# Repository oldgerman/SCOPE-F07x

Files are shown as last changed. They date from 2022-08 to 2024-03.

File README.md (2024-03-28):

# [SCOPE-F07x](https://github.com/oldgerman/SCOPE-F07x)

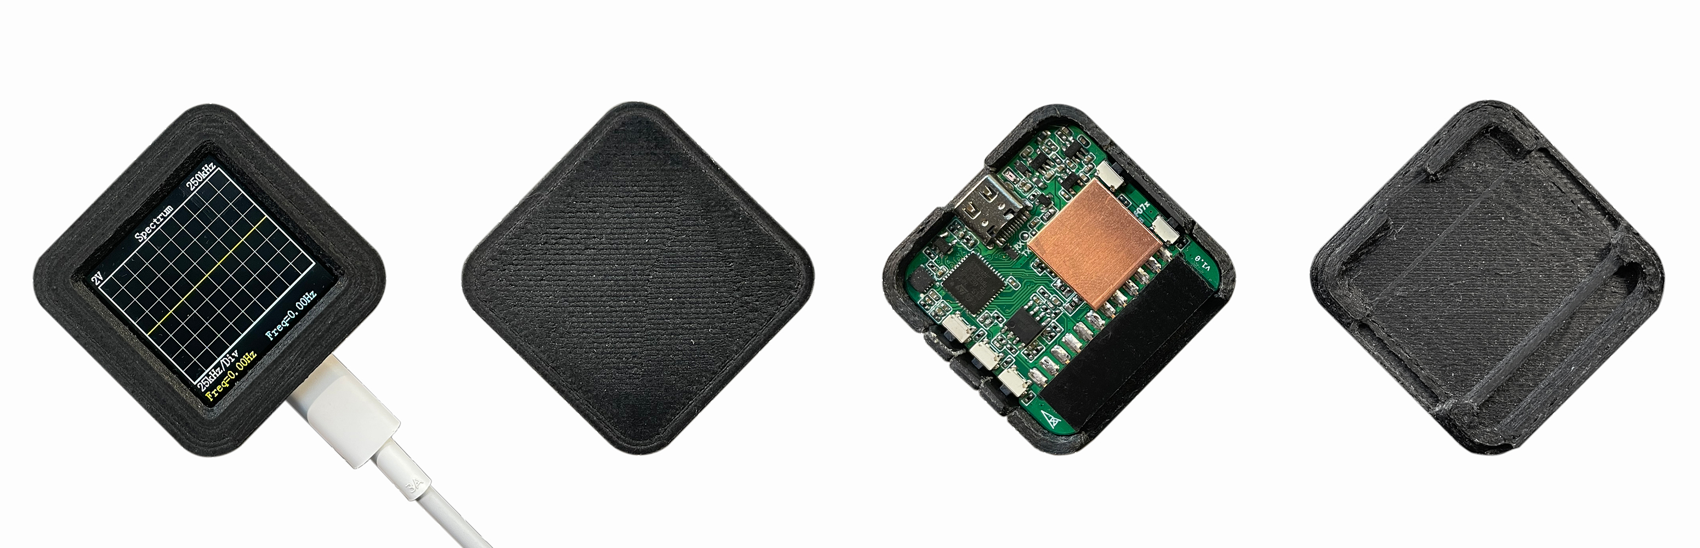
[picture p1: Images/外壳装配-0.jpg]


### 关于

[SCOPE-F07x](https://github.com/oldgerman/SCOPE-F07x) 从 [硬禾SCOPE-F072](https://github.com/EETree-git/SCOPE-F072) 开源和公开资料修改&优化

零零散散修改的地方比较多，详见修改说明部分

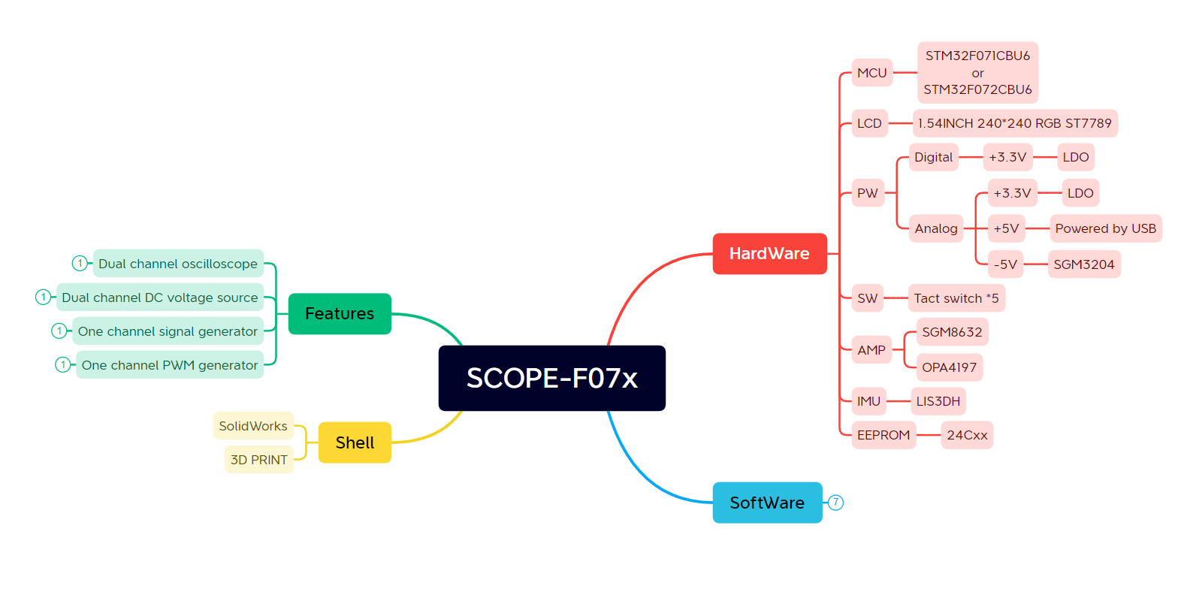
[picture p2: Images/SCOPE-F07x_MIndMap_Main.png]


### PCB

工艺：

- 层数：2
- 板厚: 1.0mm 
- 过孔: 0.3/0.5mm
- 线宽线隙: 6mil/6mil
- 尺寸: 38x38mm

封装：绝大多数是0402，物料约40多种

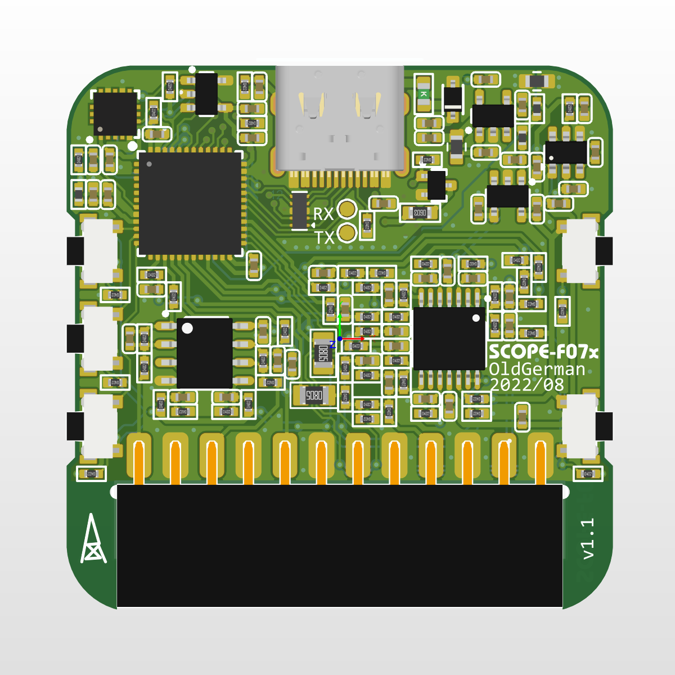
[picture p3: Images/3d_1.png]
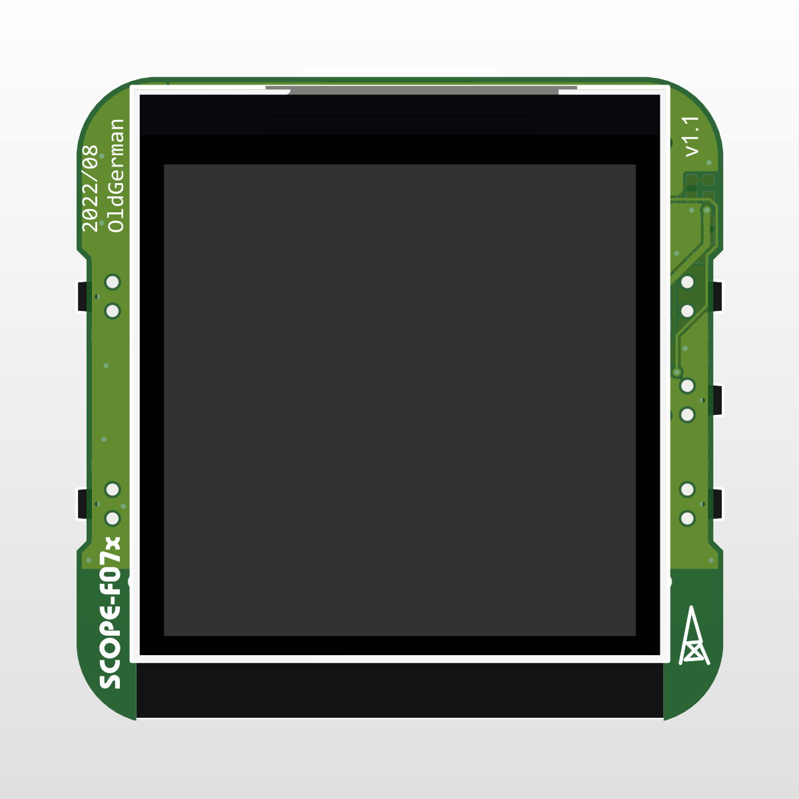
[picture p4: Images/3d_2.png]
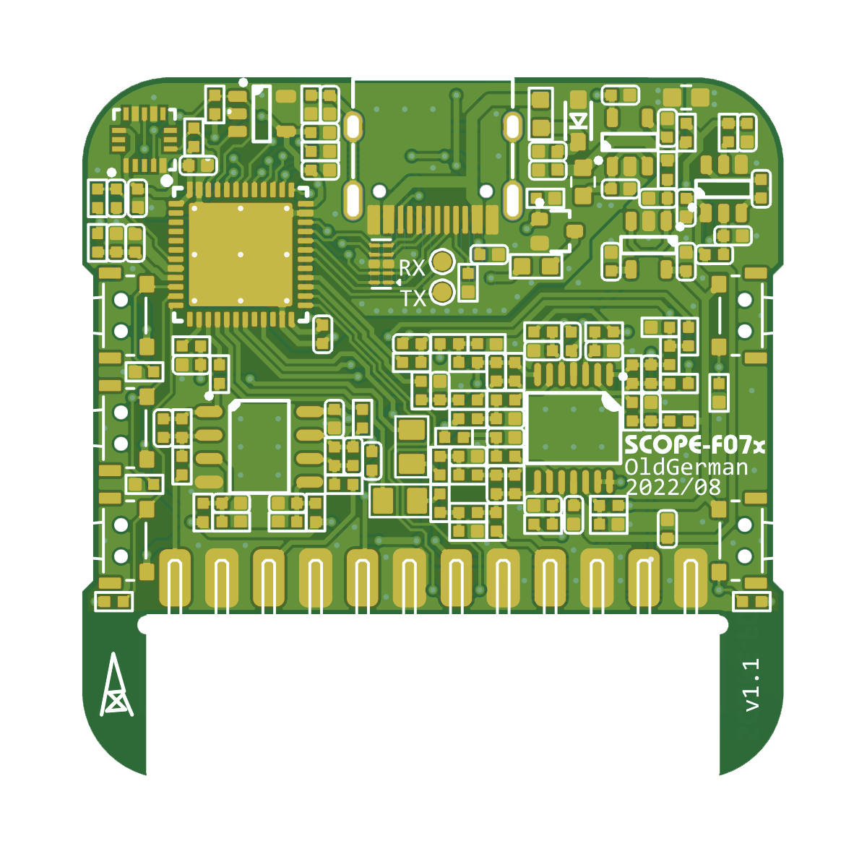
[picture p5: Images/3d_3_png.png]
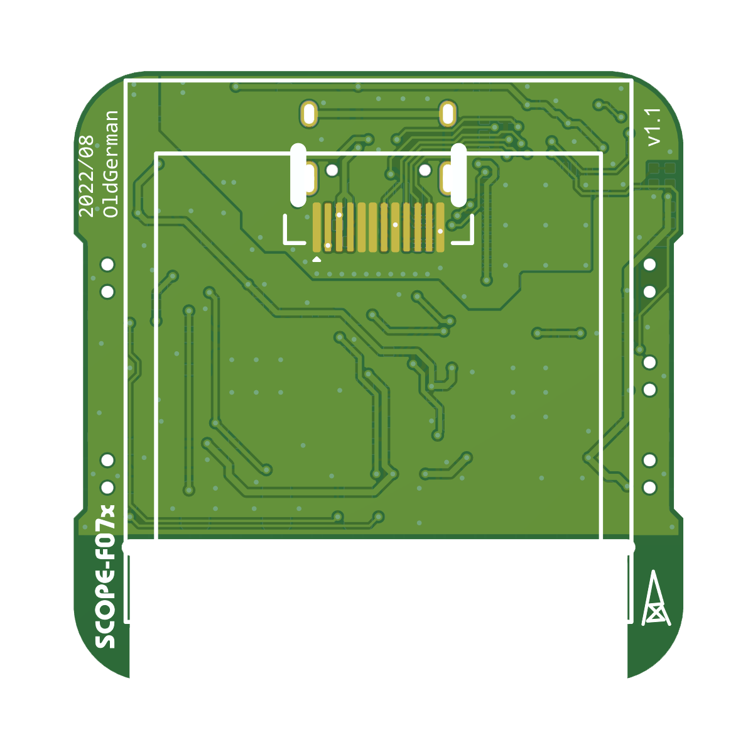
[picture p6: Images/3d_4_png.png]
|  |  |  |  |
| --- | --- | --- | --- |

### 外壳

硬禾的原始设计配套的外壳有亿点点low，出于情怀我想到经典设计 iPod nano (*6th* generation)，然而想做到这么简约并非易事

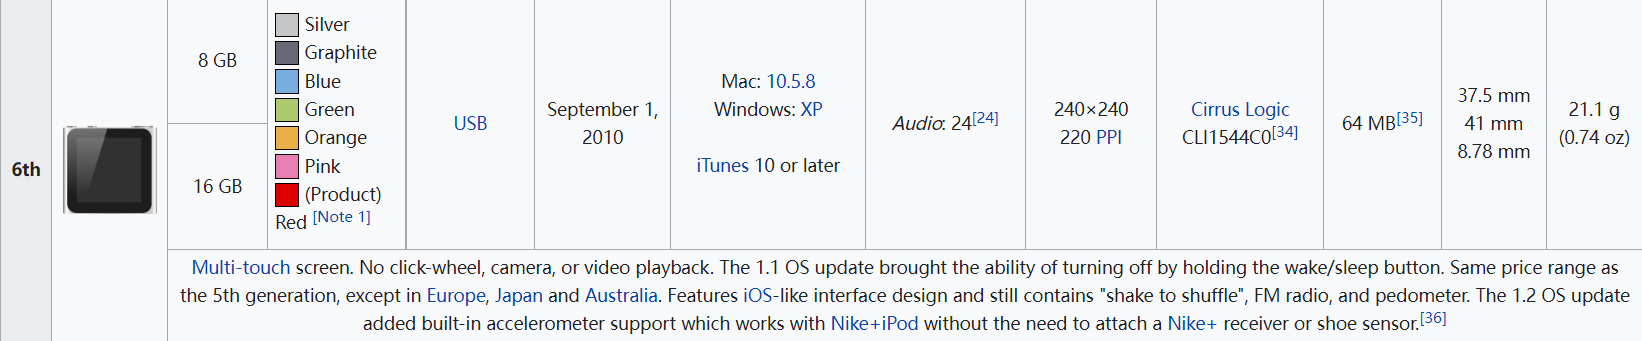
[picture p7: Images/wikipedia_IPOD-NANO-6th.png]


经过PCB和建模的各方面努力，外壳OK

- 屏幕完美居中
- 结构针对FDM成型进行了很多优化，打印全程无需支撑和拉桥
- 外壳平均厚度为2mm，免螺丝设计，纯卡扣固定，实测上下壳体卡得极其牢固

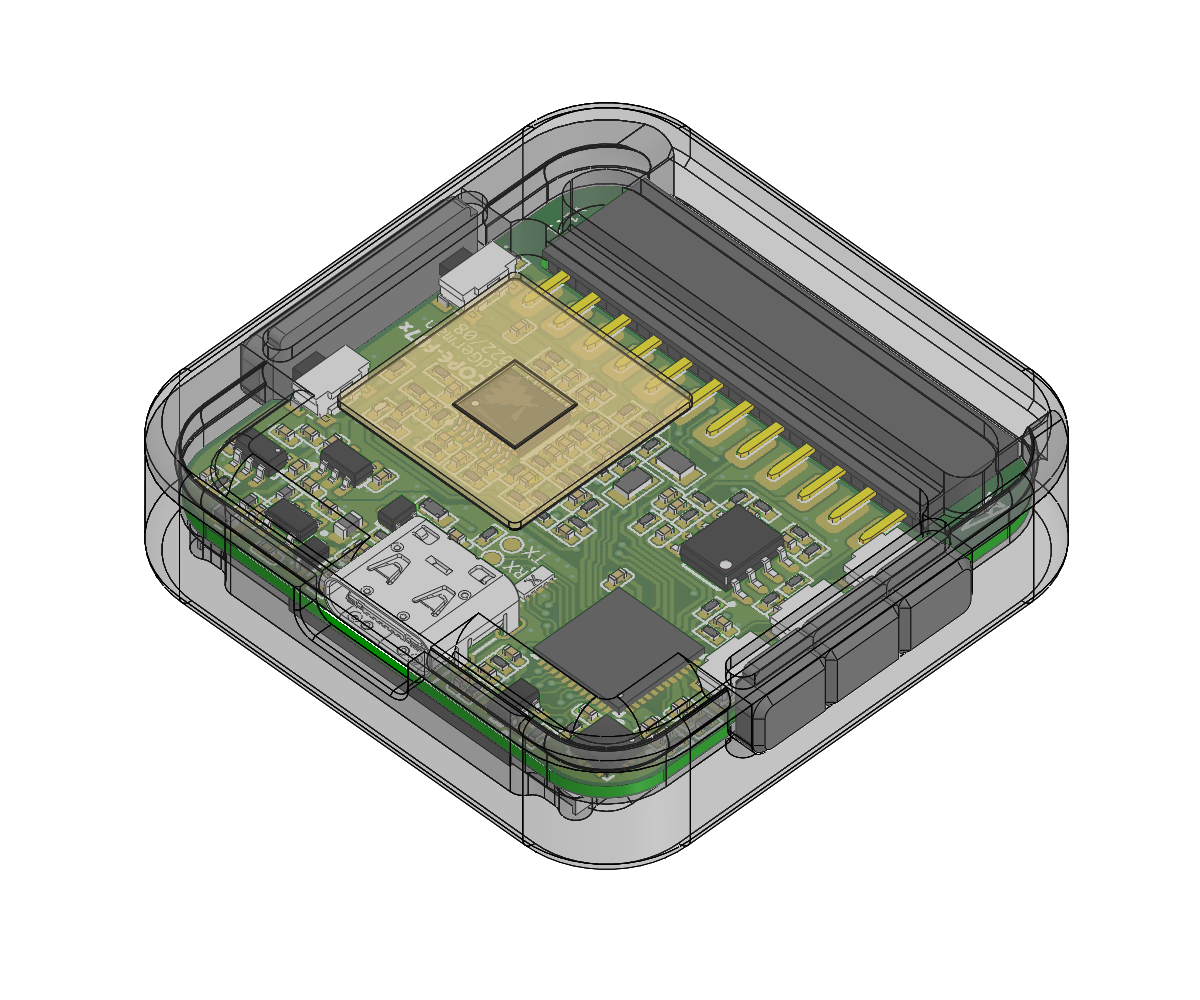
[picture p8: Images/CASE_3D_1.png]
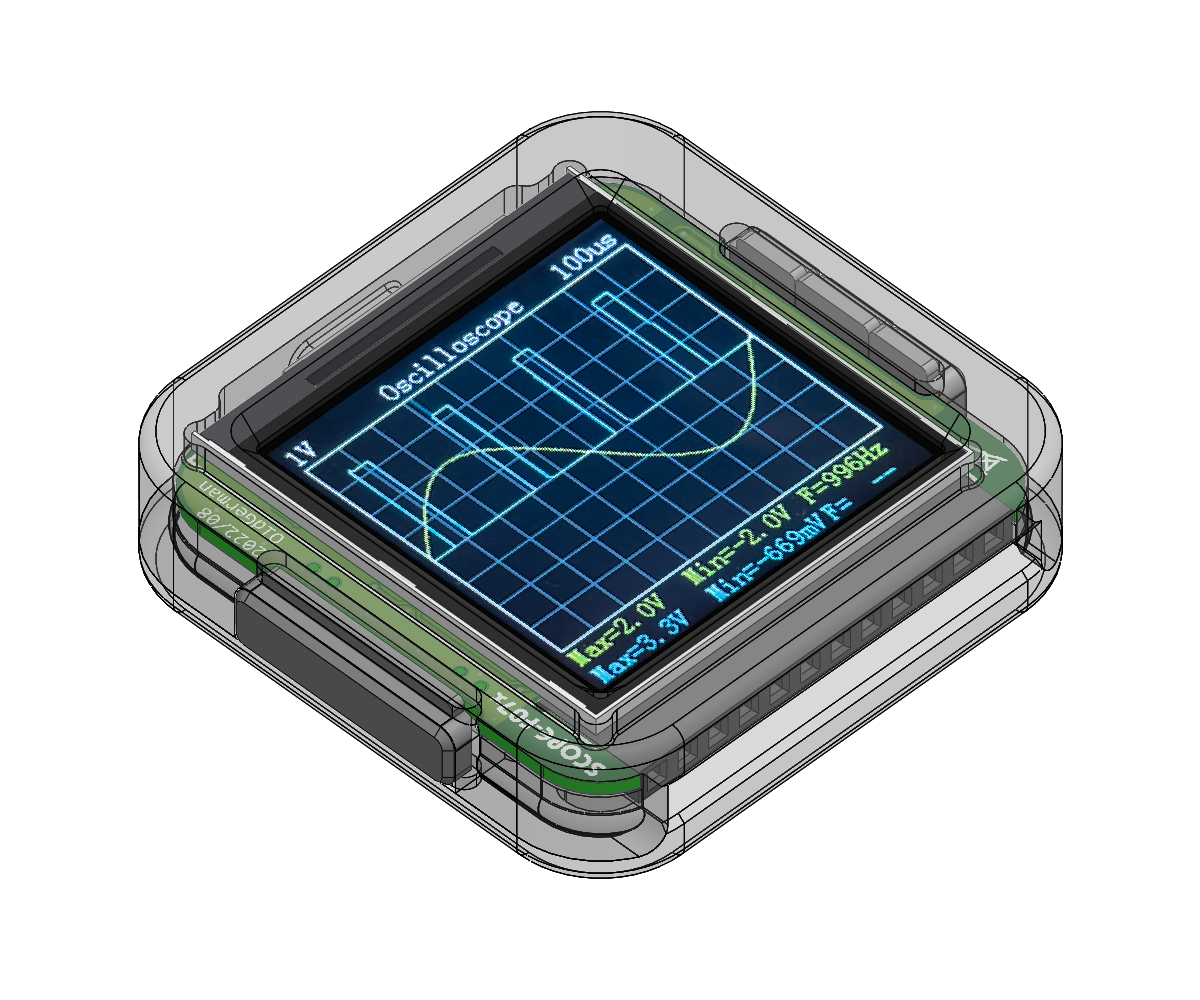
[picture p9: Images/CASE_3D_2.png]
|  |  |
| --- | --- |

一张 iPod nano 6th 海报同款角度视图 (๑•̀ㅂ•́)و✧

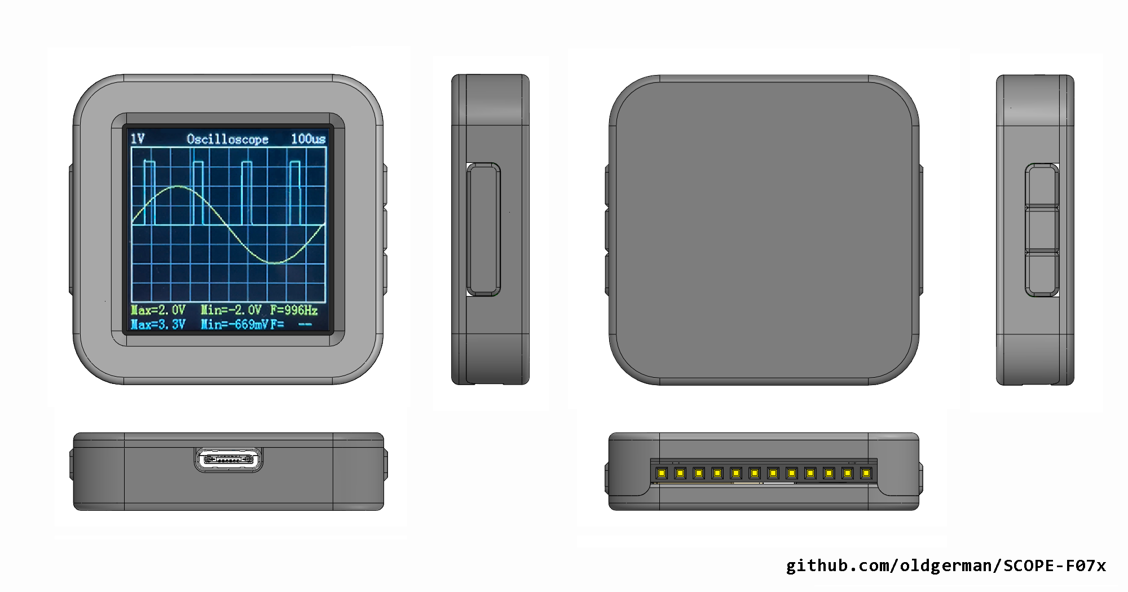
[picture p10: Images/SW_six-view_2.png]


### 散热

OPA4197其中的两个运放作为双路直流电压源，电流范围±30mA，手册 I(sink)和I(source)给的是±65mA，实测输出3.3V电压，负载电流30mA时，没有什么压降，但发热比较大，当增加到40mA开始过热/失调，电压不再稳定，因此推荐加装散热片

散热片物料：15x15x0.5mm紫铜片、3M 8810导热双面胶、金手指胶带

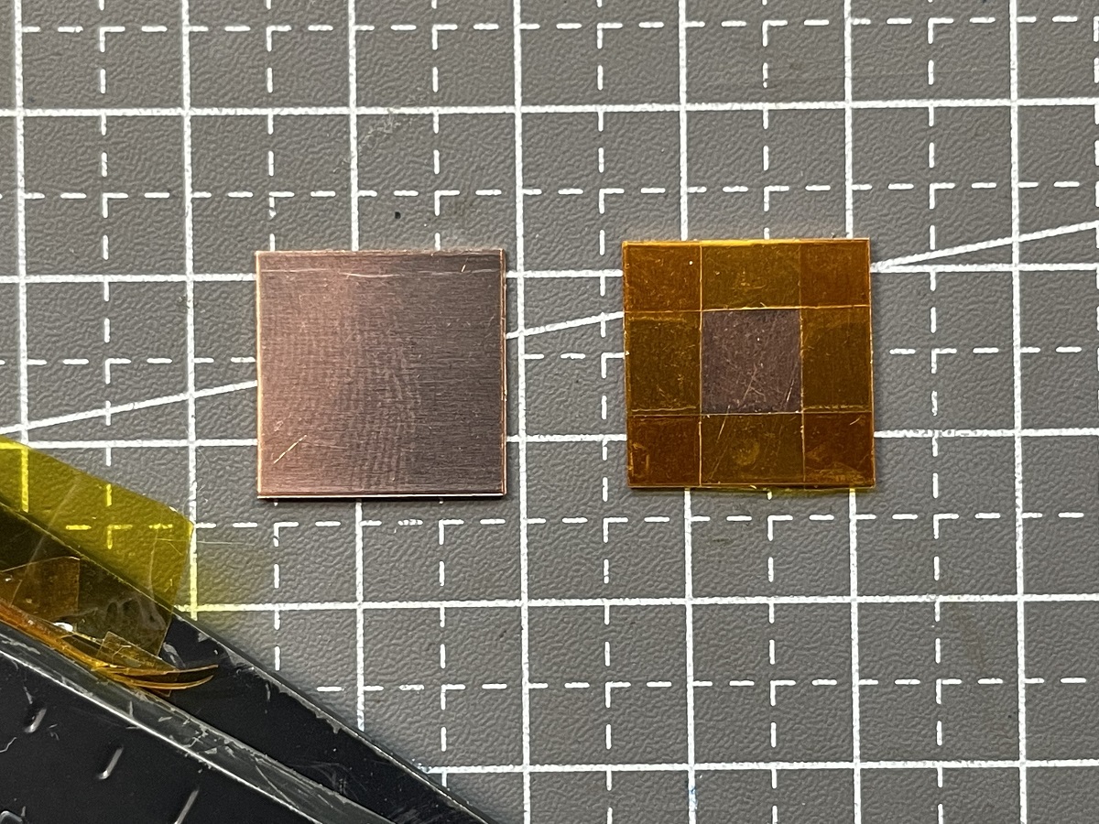
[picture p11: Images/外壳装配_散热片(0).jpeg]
外壳装配_散热片(0)
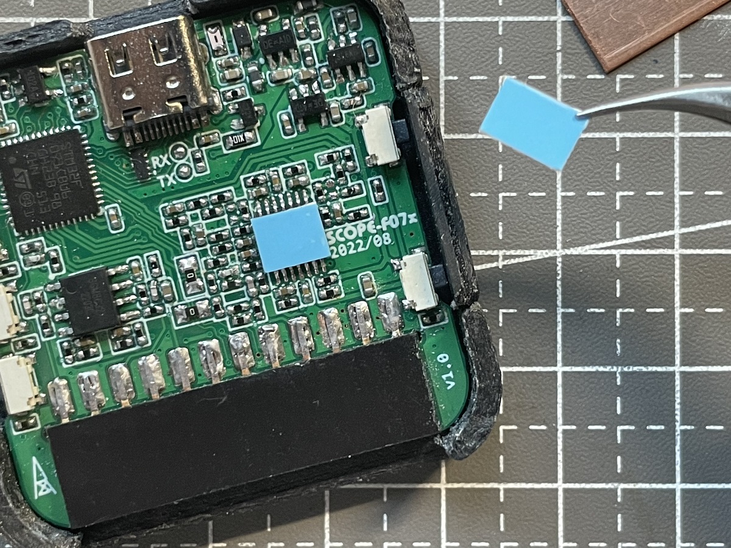
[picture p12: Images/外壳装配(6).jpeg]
外壳装配(6)
|  |  |
| --- | --- |
| OPA4197的TSSOP-14封装比较薄，保险起见可以用金手指胶带封住一部分，防止短路，虽然实际距离还挺宽裕 | 将导热胶裁剪至合适大小，之后对准中心贴上铜片即可 |

### 修改说明

#### 硬件

| 部分 | 原版 | 修改 |
| --- | --- | --- |
| Layout | STM32的模拟和数字共用电源和地，运放有个单独的3.0V电源（不明白为啥不拿这个给STM32的VDDA也供电，猜测因为STM32模拟供电电压要高于数字部分，但是3.0V又比3.3V低了0.3V不合格） | 模数电源和地分离。模拟部分电源从3.0V改为3.3V，也为STM32的VDDA供电，因为这0.3V的变化，运放电路电阻取值经过重新计算，与EEtree的技术指标保持一致 |
| USB | Miro USB，仅USB功能 | Type-c 正反插功能不同，正插USB DFU，反插可以用stlink调试（D+: SWCLK，D-: SWDIO） |
| 运放 | TP2302 | TP2302运放太冷门买不到，改为SGM8632 |
| | TL974 | TL974 I(source)太弱了只有1.5mA，改为OPA4197 |
| STM32 | STM32F072CBT6 | 换为QFN-48封装，引脚变更较多，兼容STM32F071、STM32F072，071虽然手册没写有USB但是出厂固件的 USB DFU 都有，071当072烧固件USB功能都是完整的，071就是072 |
| 电荷泵 | LM2776 | LM2776过于昂贵，换为便宜很多的SGM3204 |
| 加速度计 | MMA8653 | MMA8653又贵又冷门，换为LIS3DH，拆机的都降价到1元包邮啦 |
| EEPROM | 24C01 | 换为SOT-23封装，容量大小任意 |
| 按键 | 2个按键 + 拨轮开关 | 拨轮开关换为3个按键，一共5个按键 |

备注：其他修改细节见原理图

#### 软件

原版程序：

有好几个大的数组(成员数量几百个)，使用静态内存分配，运行时不能释放，导致固件编译后内存使用率95%以上，开Os优化编译后，Flash可用空间还有50KB以上，由于RAM剩余空间紧张，加速度计、EEPROM、屏幕背光、USB通讯、ADC反馈等相关实现被裁剪

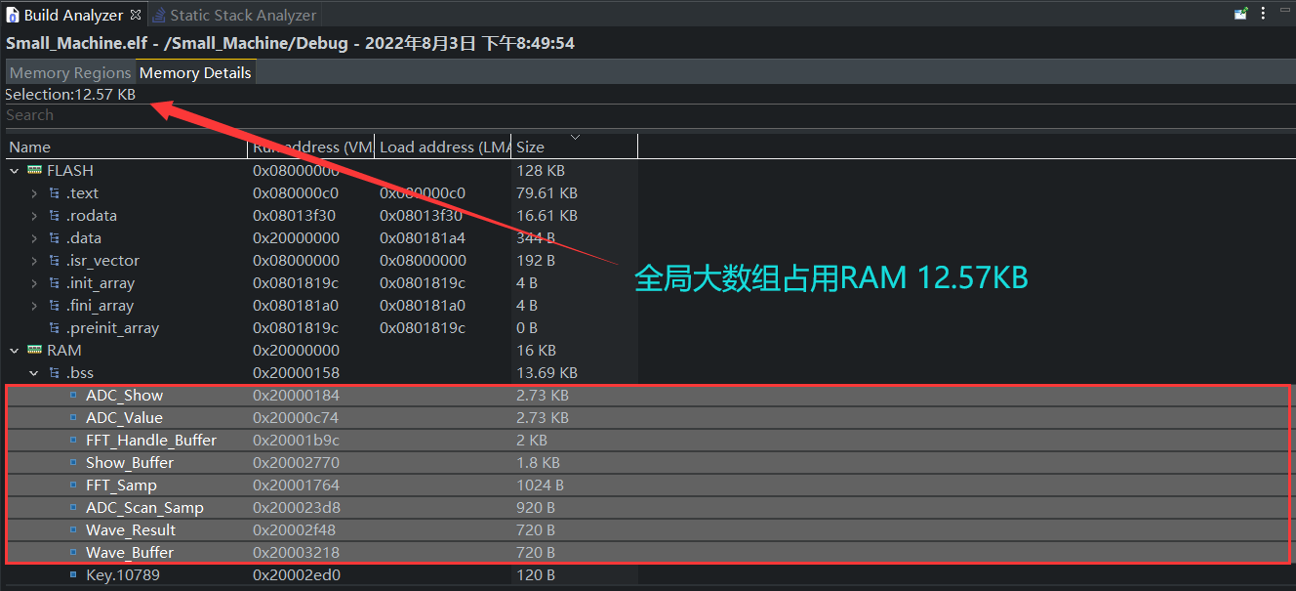
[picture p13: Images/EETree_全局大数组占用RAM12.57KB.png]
EETree_全局大数组占用RAM12.57KB


优化目标：

使用动态内存分配，尽可能实现上述被裁剪的功能

代码进度：

目前仅针对修改版PCB做了修改适配，提供工程源码文件，优化还没开始搞，代码等改好了有空再说~

### 功能测试

| 反向放大电路：提供正负电源+信号源、并测量放大后的信号  | 可调电压源双路输出20mA-30mA | 可调电压源输出负4V |
| --- | --- | --- |
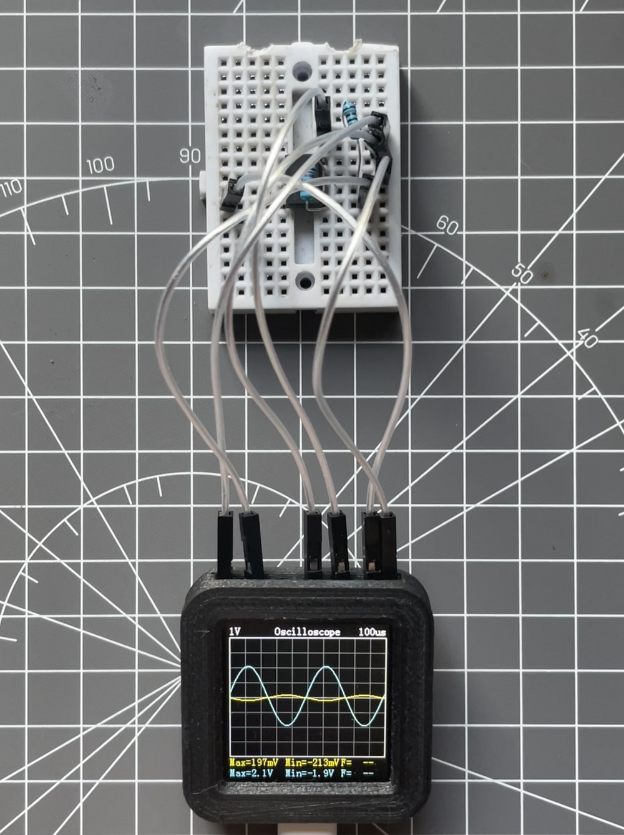
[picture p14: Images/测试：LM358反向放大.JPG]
测试：LM358反向放大
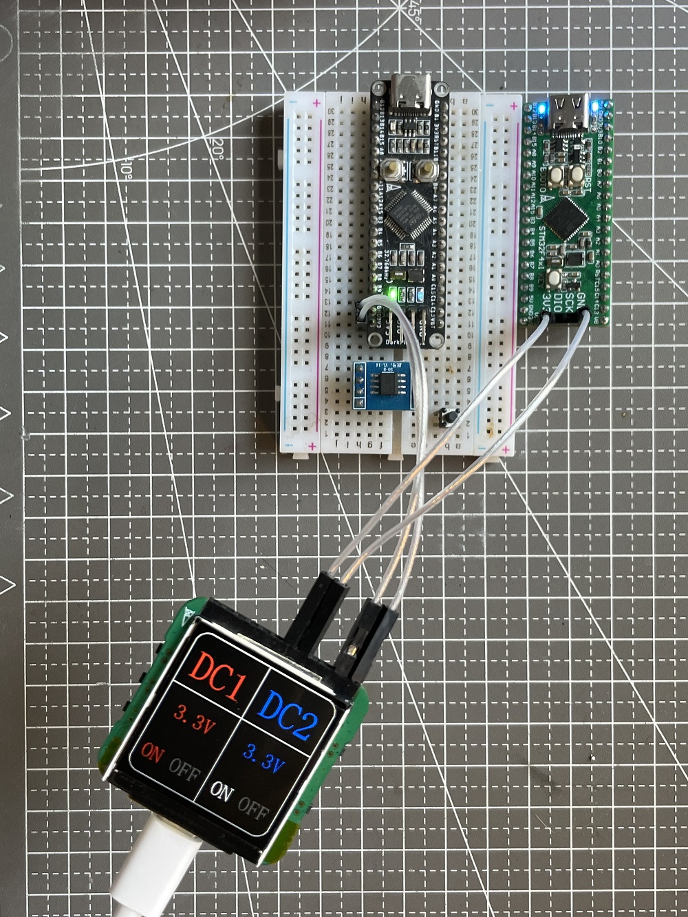
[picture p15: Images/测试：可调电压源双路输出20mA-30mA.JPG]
测试：可调电压源双路输出20mA-30mA
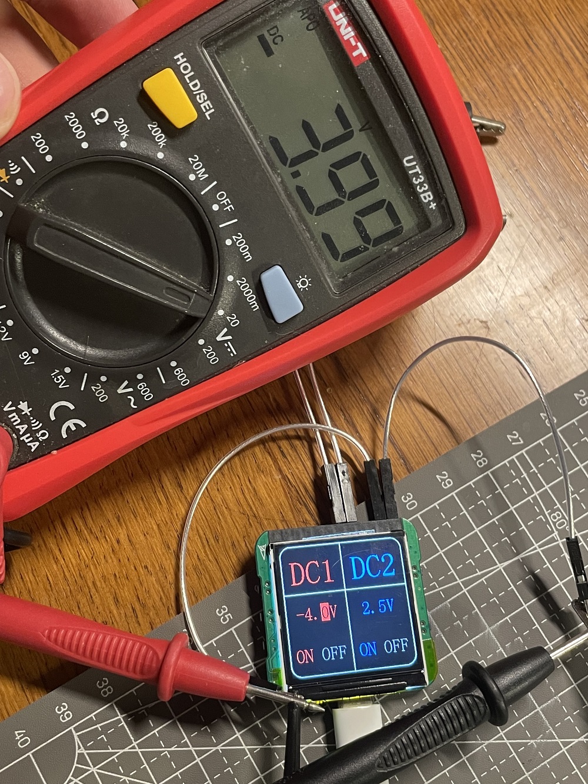
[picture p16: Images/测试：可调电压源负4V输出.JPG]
测试：可调电压源负4V输出
|  |  |  |

| 设定频率 | 设定电压 | 三角波 | 方波 | 正弦波 |
| --- | --- | --- | --- | --- |
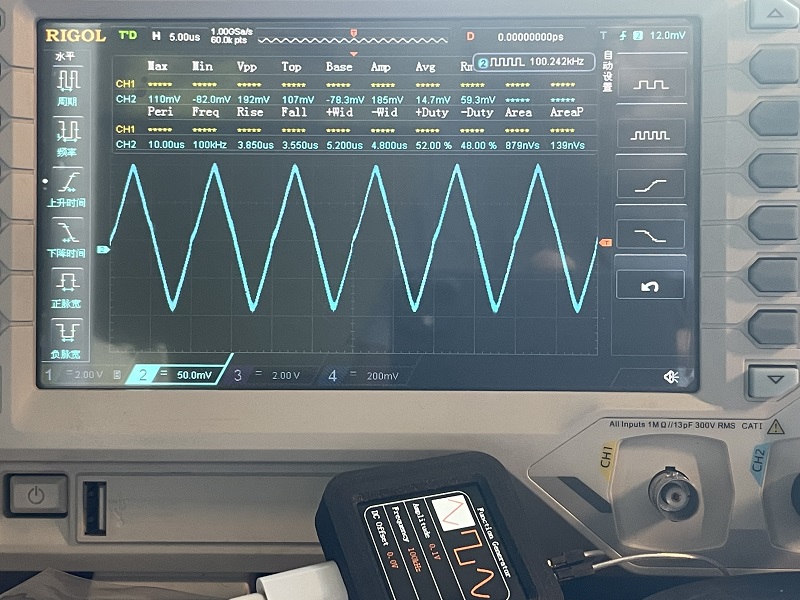
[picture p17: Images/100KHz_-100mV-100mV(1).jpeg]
100KHz_-100mV-100mV(1)
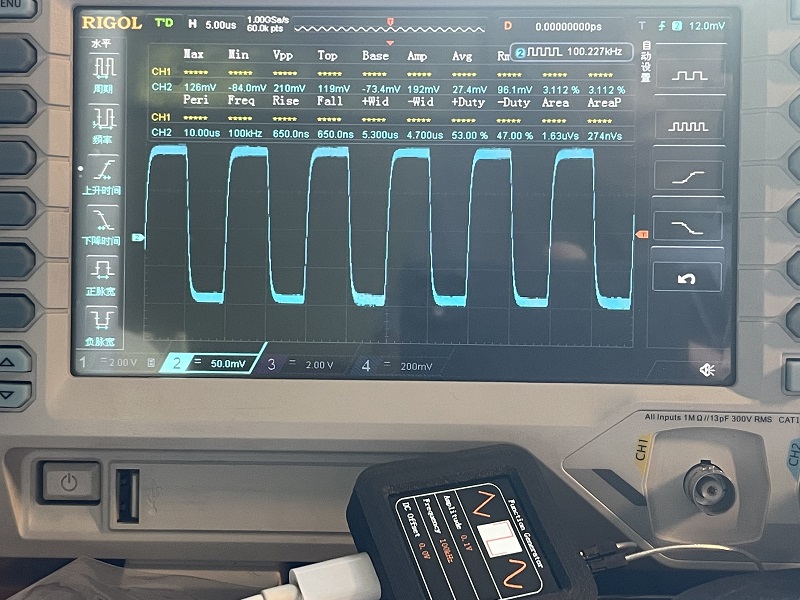
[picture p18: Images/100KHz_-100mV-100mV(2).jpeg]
100KHz_-100mV-100mV(2)
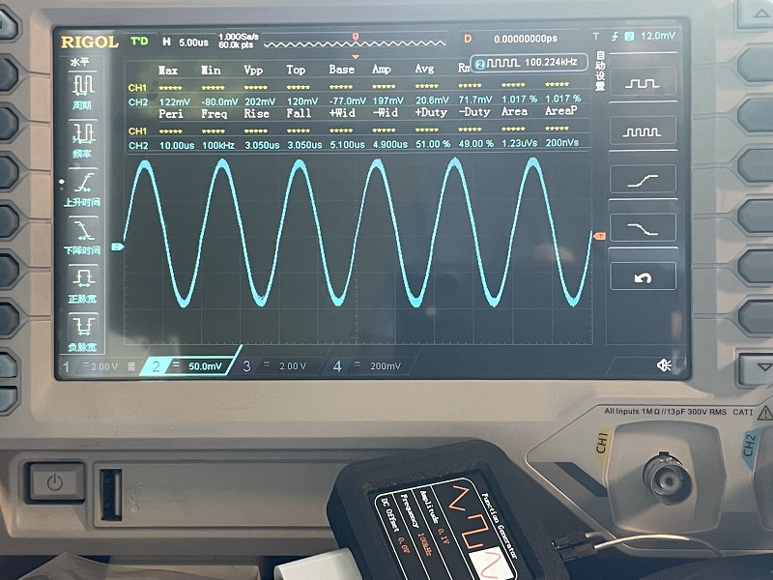
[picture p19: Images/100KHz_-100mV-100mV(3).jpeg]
100KHz_-100mV-100mV(3)
| 100KHz | ±100mV |  |  |  |
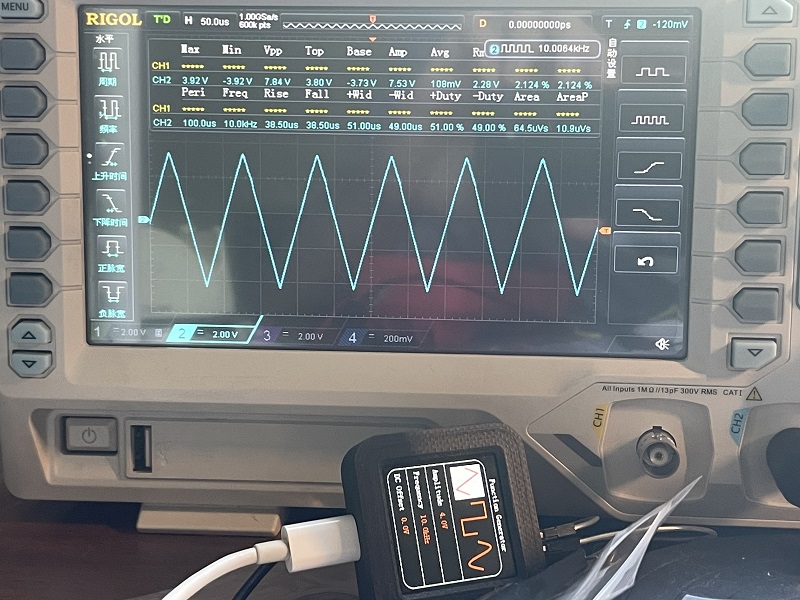
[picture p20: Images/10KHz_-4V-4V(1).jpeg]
10KHz_-4V-4V(1)
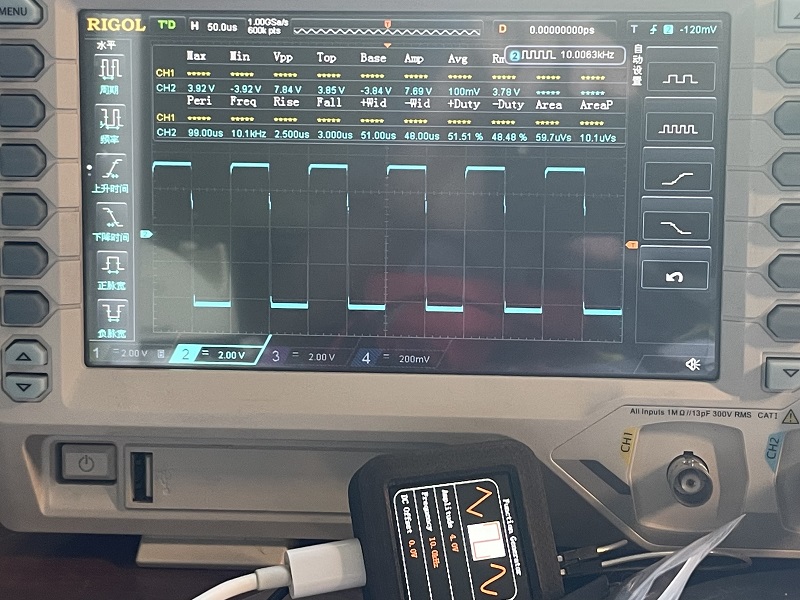
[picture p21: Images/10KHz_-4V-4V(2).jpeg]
10KHz_-4V-4V(2)
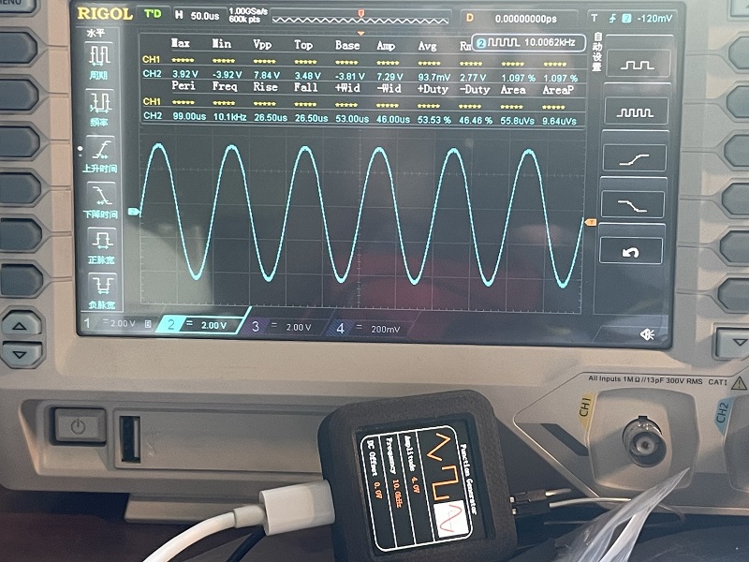
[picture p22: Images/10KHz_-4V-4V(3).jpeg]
10KHz_-4V-4V(3)
| 10KHz | ±4.0V |  |  |  |
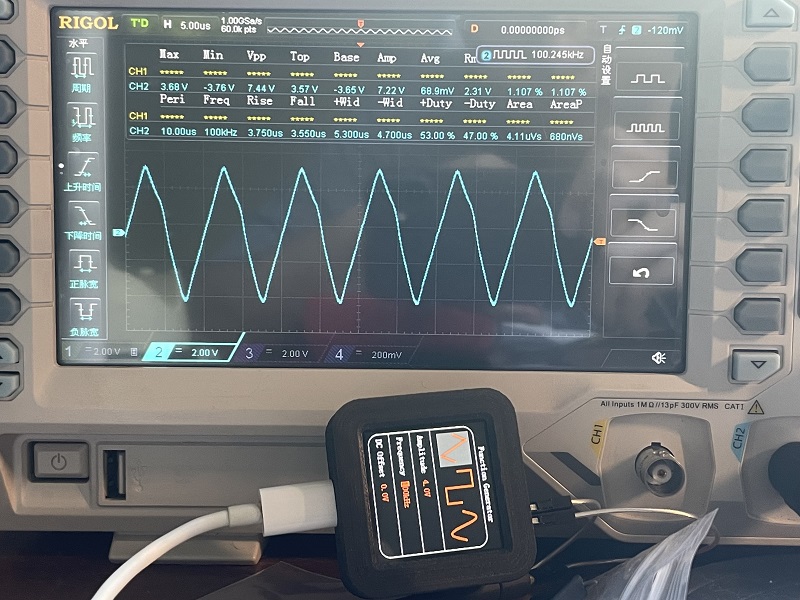
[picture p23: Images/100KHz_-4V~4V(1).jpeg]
100KHz_-4V~4V(1)
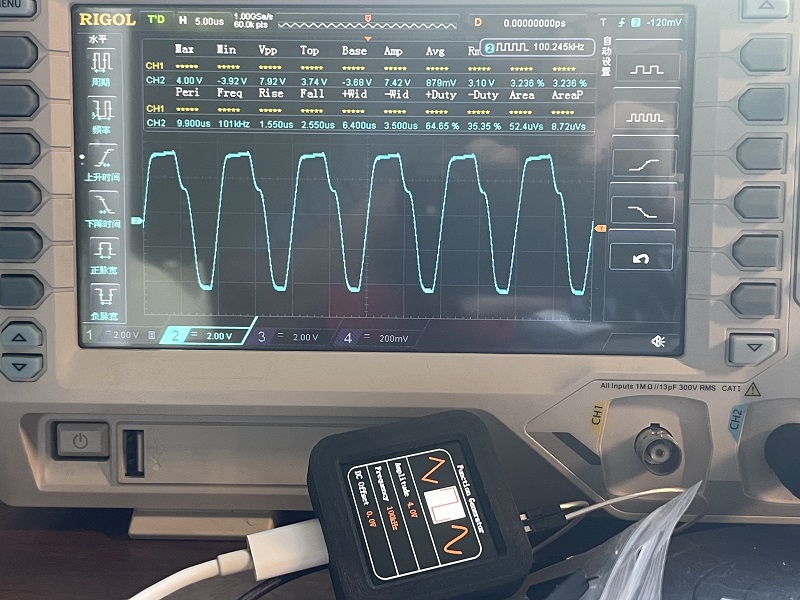
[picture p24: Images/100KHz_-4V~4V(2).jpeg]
100KHz_-4V~4V(2)
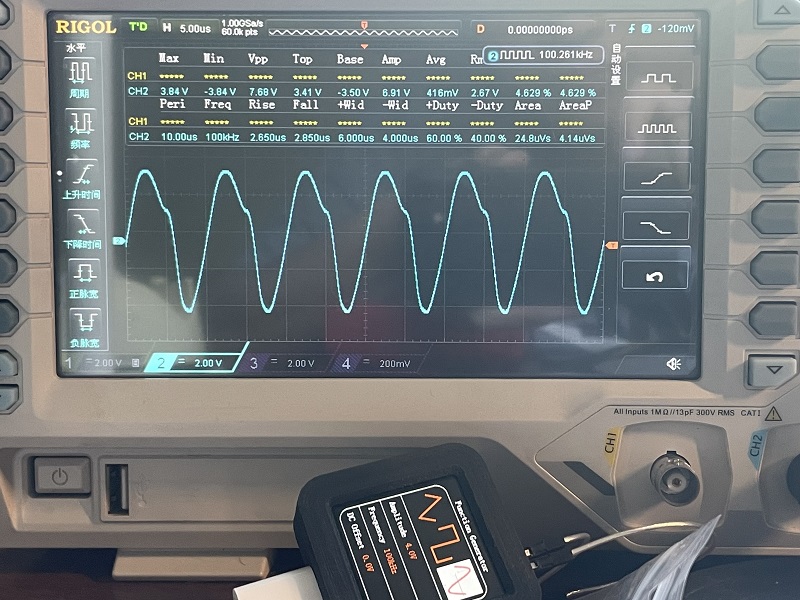
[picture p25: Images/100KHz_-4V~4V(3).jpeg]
100KHz_-4V~4V(3)
| 100KHz | ±4.0V |  |  |  |

### 其他&补充

**一些目录说明**

- [AD工程](https://github.com/oldgerman/SCOPE-F07x/tree/master/HardWare/AD_Project)：提供可编辑的源文件，软件版本2019，PDF的原理图也位于此目录

- [SW工程](https://github.com/oldgerman/SCOPE-F07x/tree/master/HardWare/SW_Project)：提供可编辑的源文件，软件版本2017

- [外壳3D打印模型](https://github.com/oldgerman/SCOPE-F07x/tree/master/HardWare/3D_Print)：STL格式提供，打印一套外壳的话，其中`SW_x3_Both_Sides_1.STL`需要打两个
- [BOM](https://github.com/oldgerman/SCOPE-F07x/tree/master/HardWare/BOM/bom)：浏览器可直接打开的交互式BOM
- [Gerber](https://github.com/oldgerman/SCOPE-F07x/tree/master/HardWare/Gerber)：整个压缩包就是
- [朋友们制作的成品展示](https://github.com/oldgerman/SCOPE-F07x/tree/master/朋友们自驾的成品)

**按键操作**

- KEY_1: 单击切换功能页面
- KEY_2: 单击切换子菜单光标
- KEY_R: 减少值或向左移动
- KEY_O: 确认或取消
- KEY_L: 增大值或向右移动

**USB DFU**

需要在未上电时按住KEY_O不放，插电进入，推荐使用STM32CubeProgrammer的USB模式烧录

### Acknowledgments

感谢硬禾团队

### License

This work is licensed under a
[Creative Commons Attribution-NonCommercial-ShareAlike 4.0 International License][cc-by-nc-sa].

[][cc-by-nc-sa]

[cc-by-nc-sa]: http://creativecommons.org/licenses/by-nc-sa/4.0/
[cc-by-nc-sa-image]: https://i.creativecommons.org/l/by-nc-sa/4.0/88x31.png

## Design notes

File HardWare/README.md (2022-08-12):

## AD工程

软件版本2019

## SW工程

软件版本2017

## 3D打印模型

3D_Print文件夹STL格式提供，打印一套外壳的话，其中SW_x3_Both_Sides_1需要打两个

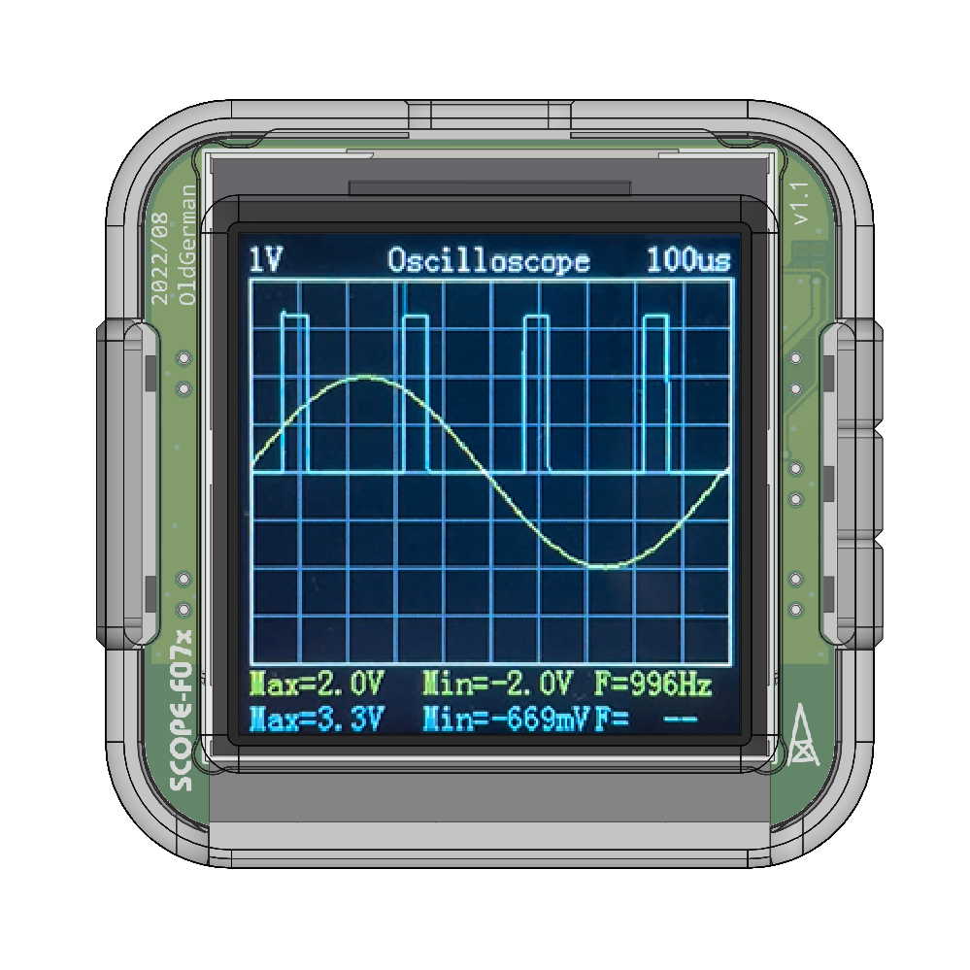
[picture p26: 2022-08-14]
Images/CASE_3D_4.png

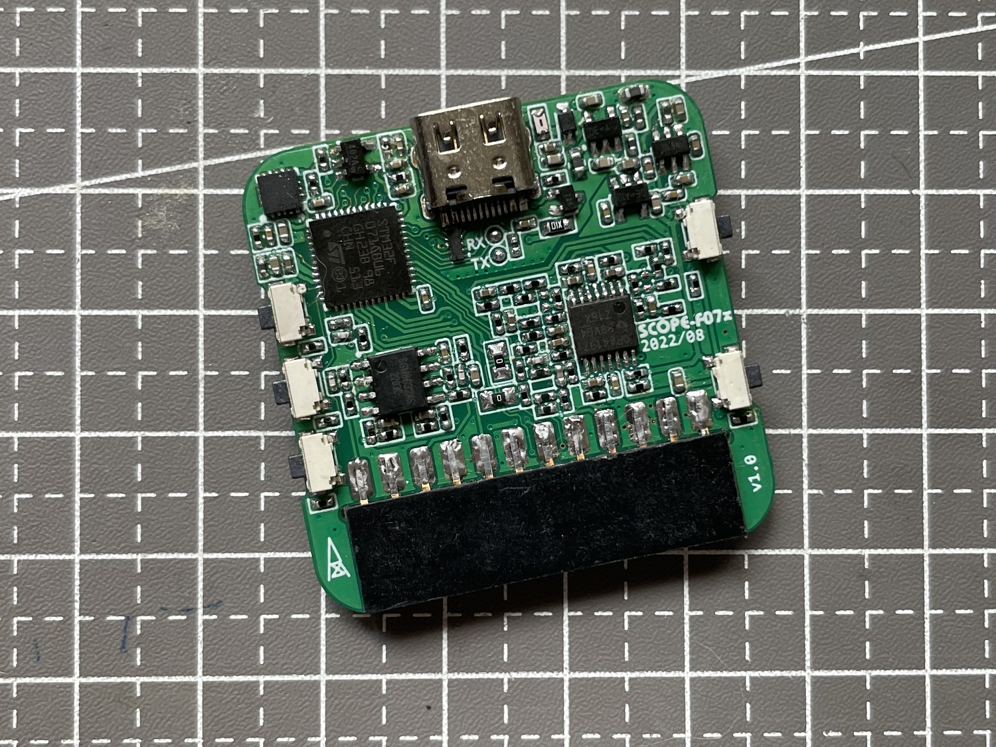
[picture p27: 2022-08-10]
Images/SCOPE-F07x_v1.0_初号机.JPG

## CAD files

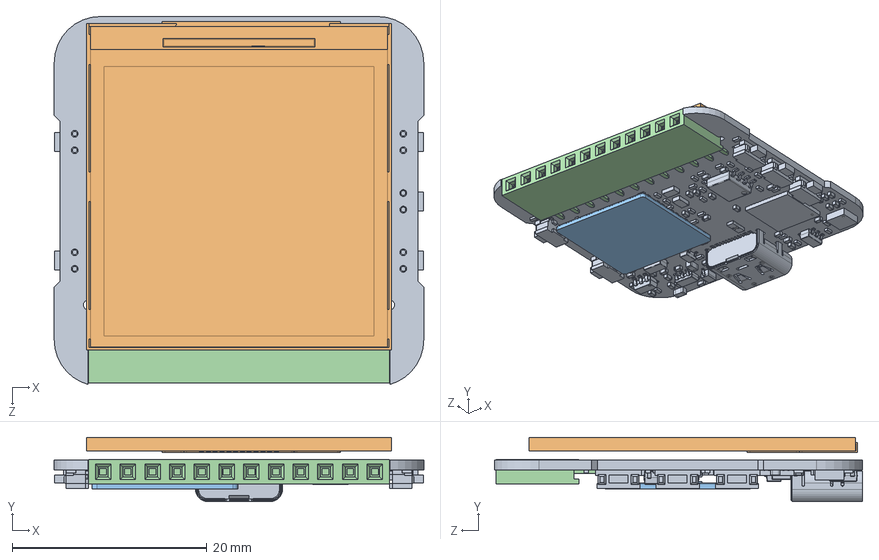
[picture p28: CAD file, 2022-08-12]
HardWare/SW_Project/SCOPE_PCB_ALL.SLDASM
38.0 x 6.58 x 37.8 mm
Scope_PCB-AD
1.54 TFT IPS-12P-Flat Flush Mount
紫铜片_15x15x0.5mm
2.54MM_Pin Header_Female_1x12

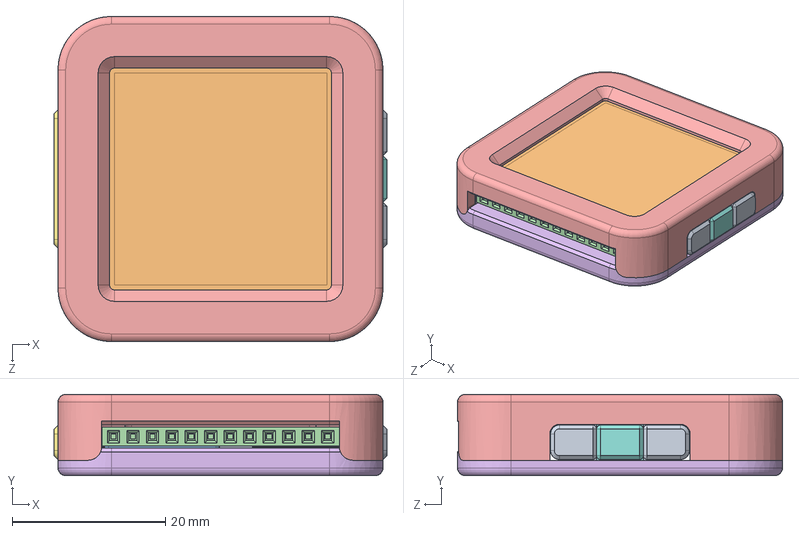
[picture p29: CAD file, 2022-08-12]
HardWare/SW_Project/SCOPE_ALL_Project1.SLDASM
43.4 x 10.6 x 42.4 mm
Scope_PCB-AD
1.54 TFT IPS-12P-Flat Flush Mount
紫铜片_15x15x0.5mm
2.54MM_Pin Header_Female_1x12
CASE_TOP_1
CASE_BOTTOM_1
按键_x2_1
按键_x3_中间_1
按键_x3_两边_1 x 2

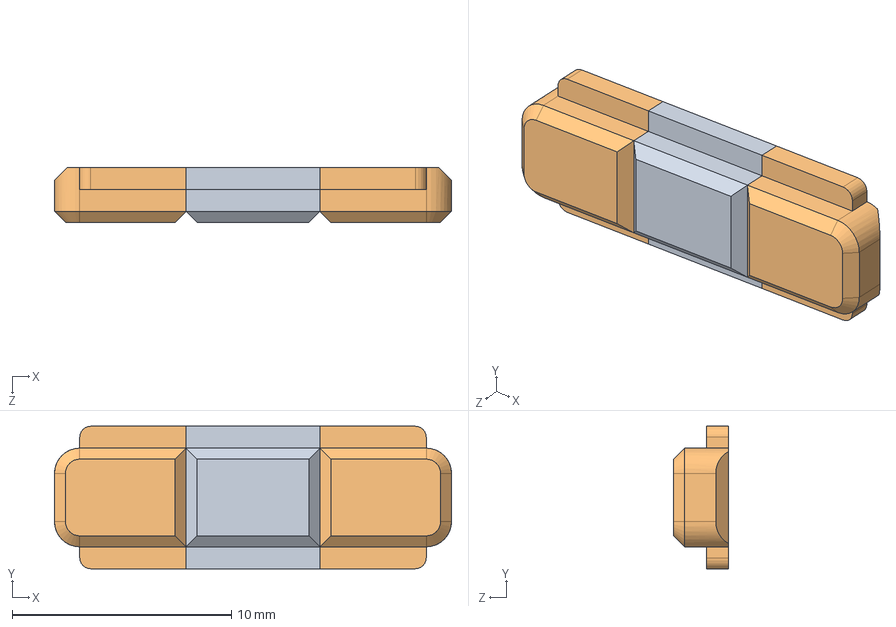
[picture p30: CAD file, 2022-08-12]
HardWare/SW_Project/按键x3_1.SLDASM
18.1 x 6.50 x 2.50 mm
按键_x3_中间_1
按键_x3_两边_1 x 2

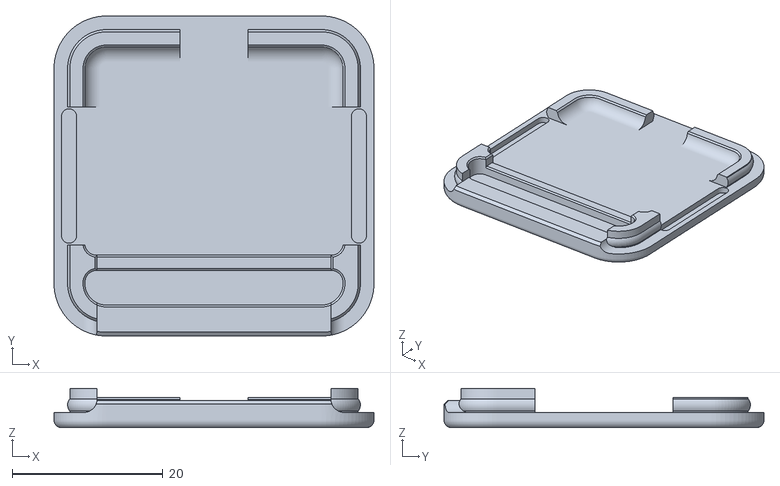
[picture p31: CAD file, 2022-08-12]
HardWare/3D_Print/CASE_BOTTOM_1_0812-1232.STL
42.4 x 42.4 x 5.20

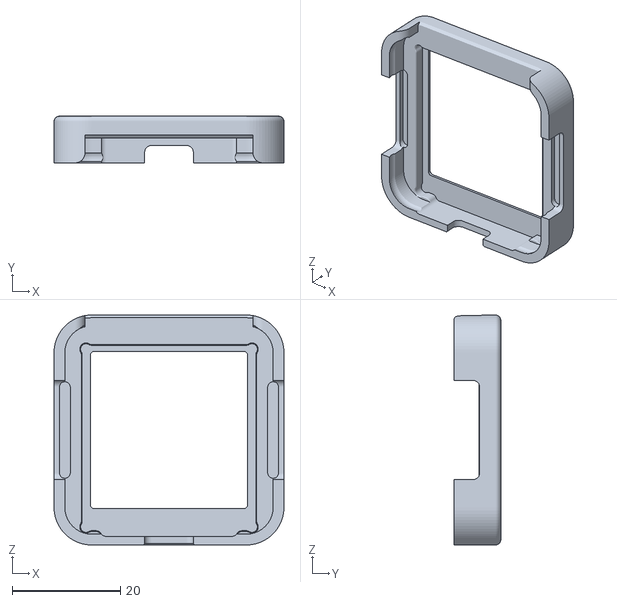
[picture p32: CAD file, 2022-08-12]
HardWare/3D_Print/CASE_TOP_1_0812_1233.STL
42.4 x 8.60 x 42.4

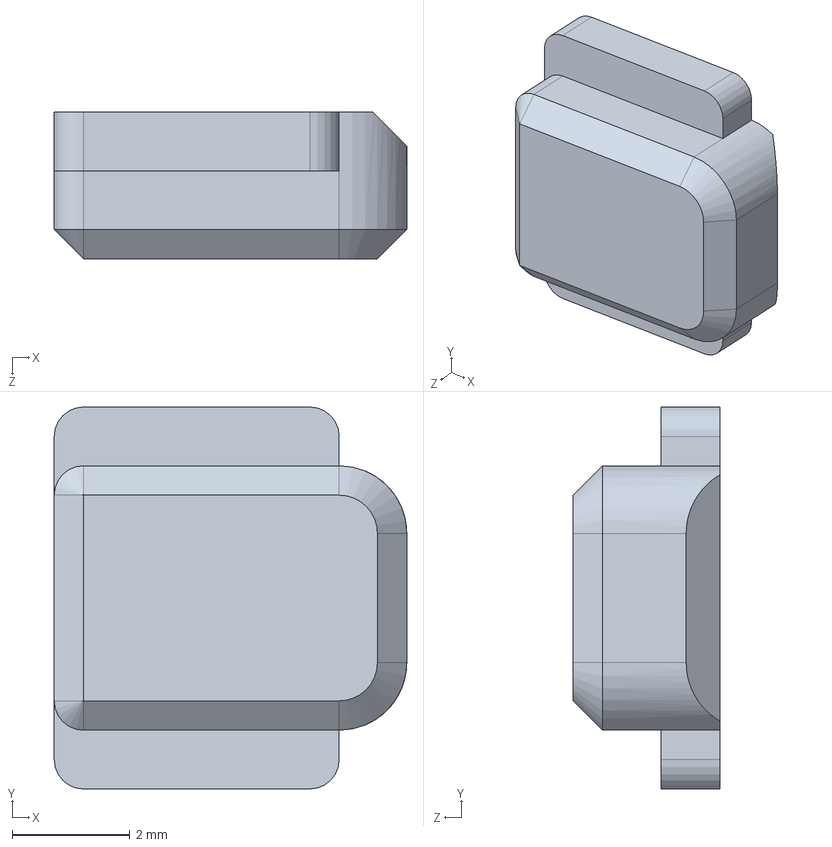
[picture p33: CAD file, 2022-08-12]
HardWare/SW_Project/按键_x3_两边_1.SLDPRT
6.00 x 6.50 x 2.50 mm

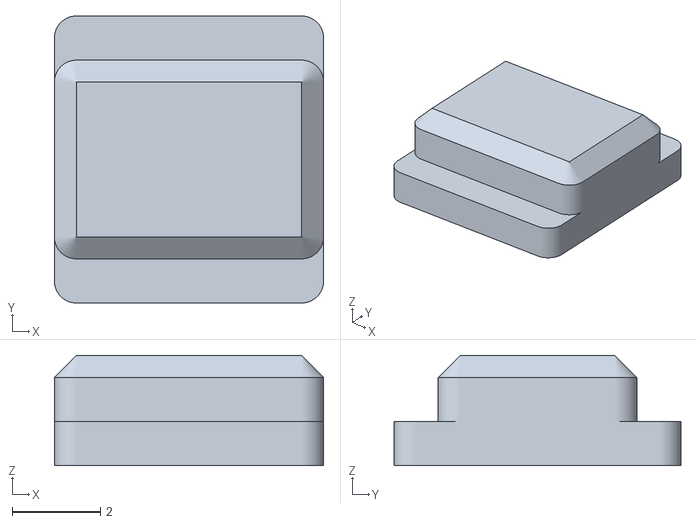
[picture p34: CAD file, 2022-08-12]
HardWare/3D_Print/SW_x3_Center_1.STL
6.10 x 6.50 x 2.50

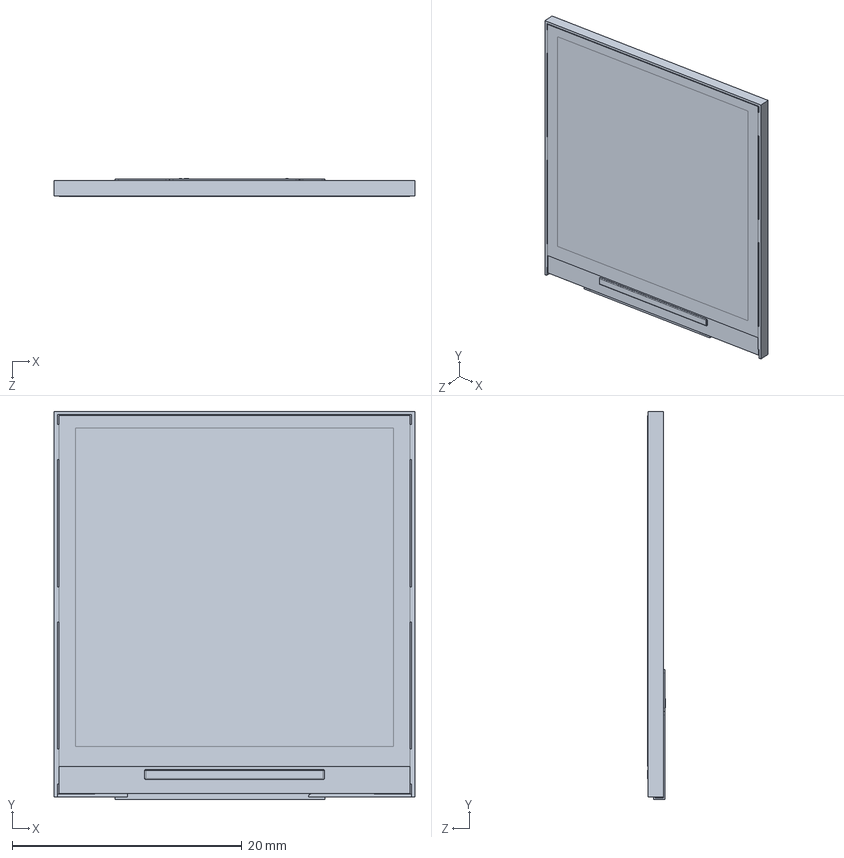
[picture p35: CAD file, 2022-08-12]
HardWare/SW_Project/1.54 TFT IPS-12P-Flat Flush Mount.SLDPRT
31.4 x 33.8 x 1.54 mm

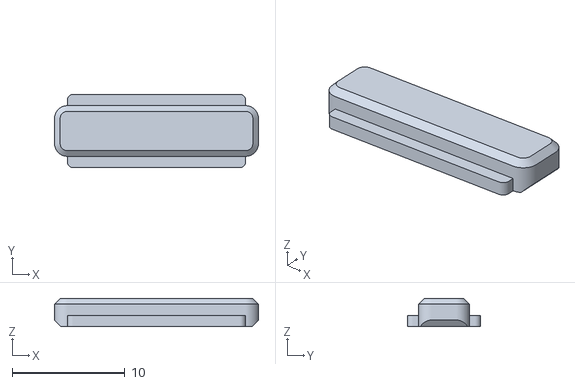
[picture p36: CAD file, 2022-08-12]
HardWare/3D_Print/SW_x2_1.STL
18.1 x 6.50 x 2.50

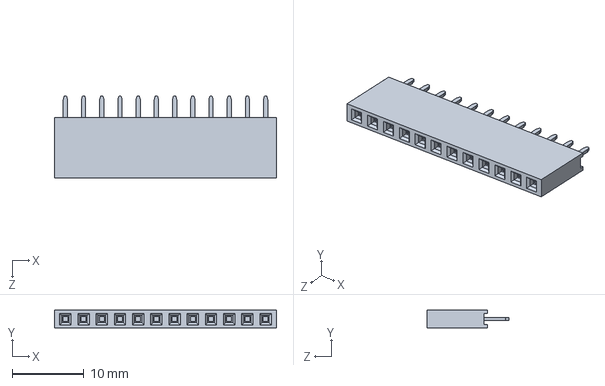
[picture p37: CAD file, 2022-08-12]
HardWare/SW_Project/2.54MM_Pin Header_Female_1x12.SLDPRT
31.0 x 2.50 x 11.5 mm

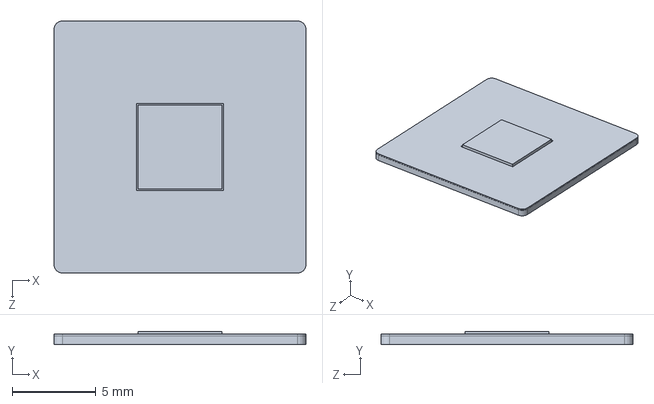
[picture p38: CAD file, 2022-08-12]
HardWare/SW_Project/紫铜片_15x15x0.5mm.SLDPRT
15.0 x 0.76 x 15.0 mm

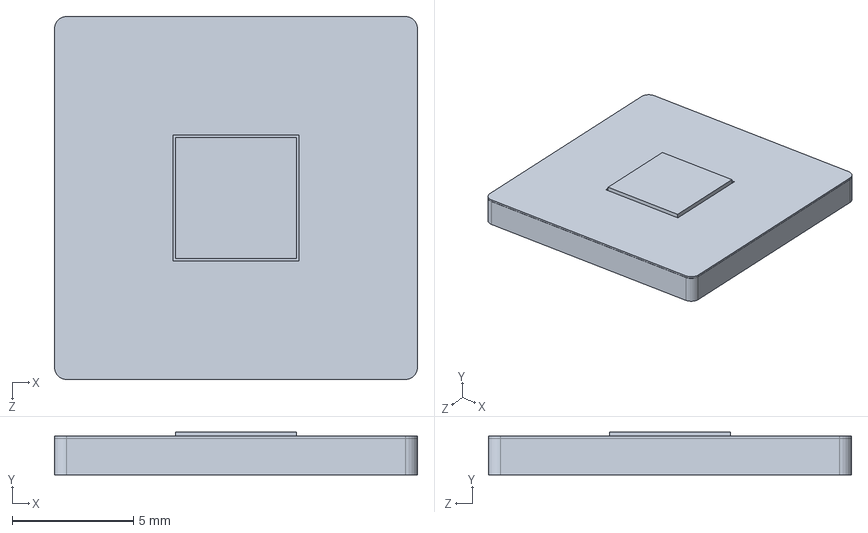
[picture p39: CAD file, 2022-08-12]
HardWare/SW_Project/紫铜片_15x15x1.5mm.SLDPRT
15.0 x 1.76 x 15.0 mm

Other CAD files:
HardWare/3D_Print/SW_x3_Both_Sides_1.STL
HardWare/SW_Project/CASE_BOTTOM_1.SLDPRT
HardWare/SW_Project/按键_x2_1.SLDPRT
HardWare/SW_Project/CASE_TOP_1.SLDPRT
HardWare/SW_Project/按键_x3_中间_1.SLDPRT
HardWare/SW_Project/IPOD NANO 6 尺寸逆向.SLDPRT

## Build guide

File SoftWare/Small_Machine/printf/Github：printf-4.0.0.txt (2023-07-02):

仓库链接
https://github.com/mpaland/printf
https://github.com/mpaland/printf
https://github.com/mpaland/printf

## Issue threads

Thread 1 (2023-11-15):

请教一下制作中出现的问题

cccll33, 2023-11-15:
首先谢谢分享，小工具设计的非常可爱。

制作过程中有些问题请教下，通道1、2 悬空时，示波页面底部显示两通道电压均为4.5V左右，接自身波形发生（2V,10KHz,0V）时，示波页面通道电压值为MAX:5V  MIN:2.2V，测量SGM8632两个输出脚电压均为0.18V，主控071cbu6，程序版本2023-0426-0233，请问以上可能是哪里的问题，该如何排查。

cccll33, 2023-11-15:
补充：万用表测量板上两个3.3V正常，5V正常，-5V正常，1.65V正常，两路DC输出电压正常。PCB版本1.1

cccll33, 2023-11-15:
补充2：上述测量SGM8632输出脚（1脚 7脚）电压0.18V，是在通道1、2悬空状态下。SGM8632输入引脚（2脚 6脚）电压0.2V。
另附通道1接自身波形发生（2V，10KHz，0V）图
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

cccll33, 2023-11-16:
排查到了，是8632的输入分压电阻焊错了，发现时看着全新未拆封的5.49K陷入了沉思。焊成了54.9K.
再次感谢分享，再次表示设计的非常可爱，小巧且实用。

oldgerman, 2024-01-07:
很高兴这个不起眼的小玩具能给你带来实用性，祝贺你下车成功哈哈，您太客气了
（不好意思哈，我的谷歌邮箱常年广告邮件淹没了，刚才整理才看见你的issue）

Closed 2024-01-07.

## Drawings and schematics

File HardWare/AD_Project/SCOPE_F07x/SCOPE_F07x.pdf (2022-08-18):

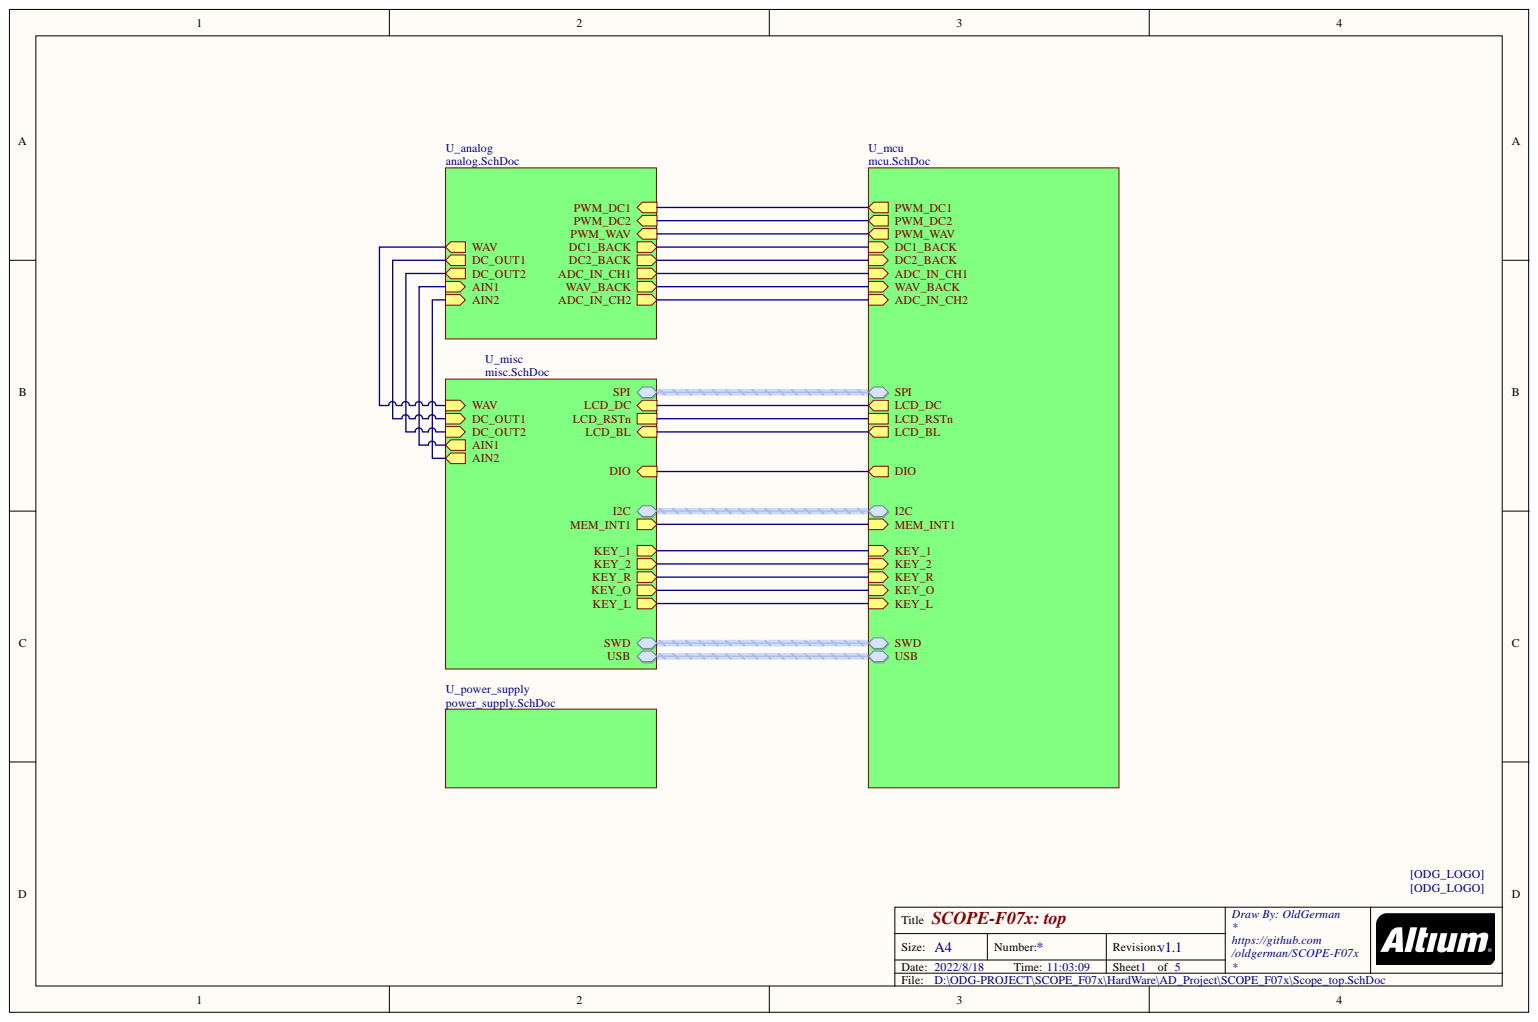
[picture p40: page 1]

SCOPE-F07x: top Title | Draw By: OldGerman * https://github.com/oldgerman/SCOPE-F07x

A4 Size: | * Number: | v1.1 Revision:
Date: 2022/8/18 Time: 11:03:09 | | Sheet of

D:\ODG-PROJECT\SCOPE_F07x\HardWare\AD_Project\SCOPE_F07x\Scope_top.SchDoc

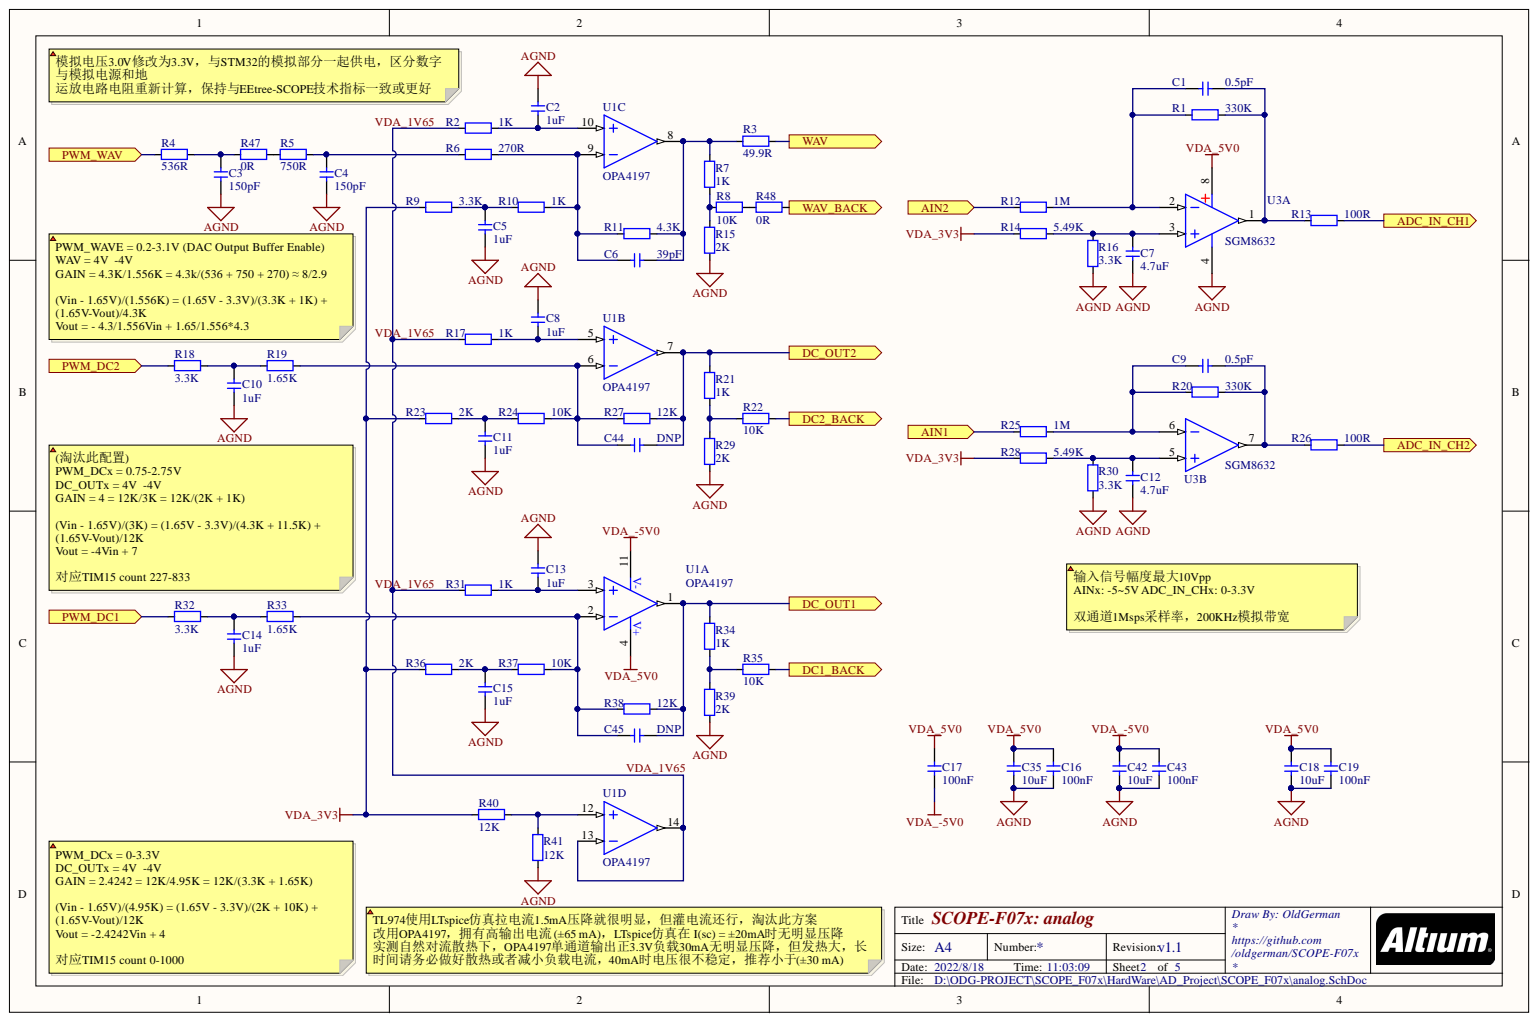
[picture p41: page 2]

PWM_WAVE = 0.2-3.1V (DAC Output Buffer Enable)
WAV = 4V -4V
GAIN = 4.3K/1.556K = 4.3k/(536 + 750 + 270) ≈ 8/2.9

SCOPE-F07x: analog Title | Draw By: OldGerman * https://github.com/oldgerman/SCOPE-F07x

TL974使用LTspice仿真拉电流1.5mA压降就很明显，但灌电流还行，淘汰此方案
改用OPA4197，拥有高输出电流 (±65 mA)，LTspice仿真在 I(sc) = ±20mA时无明显压降
实测自然对流散热下，OPA4197单通道输出正3.3V负载30mA无明显压降，但发热大，长
时间请务必做好散热或者减小负载电流，40mA时电压很不稳定，推荐小于(±30 mA)

A4 Size: | * Number: | v1.1 Revision:

D:\ODG-PROJECT\SCOPE_F07x\HardWare\AD_Project\SCOPE_F07x\analog.SchDoc

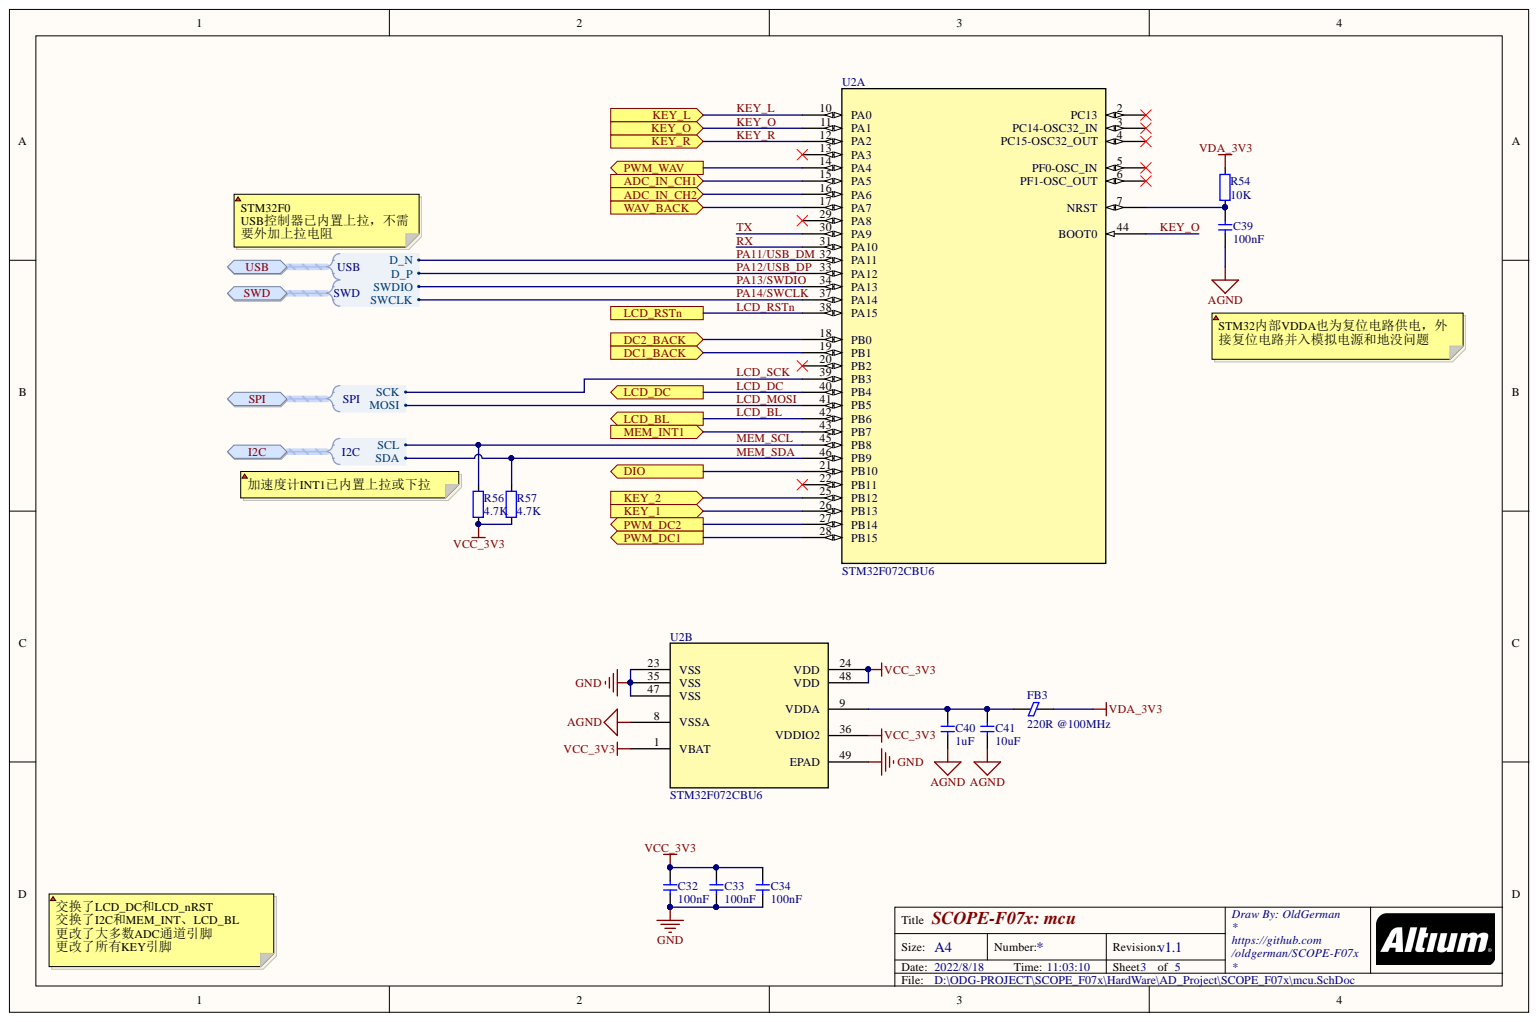
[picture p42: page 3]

SCOPE-F07x: mcu Title | Draw By: OldGerman * https://github.com/oldgerman/SCOPE-F07x

A4 Size: | * Number: | v1.1 Revision:

D:\ODG-PROJECT\SCOPE_F07x\HardWare\AD_Project\SCOPE_F07x\mcu.SchDoc

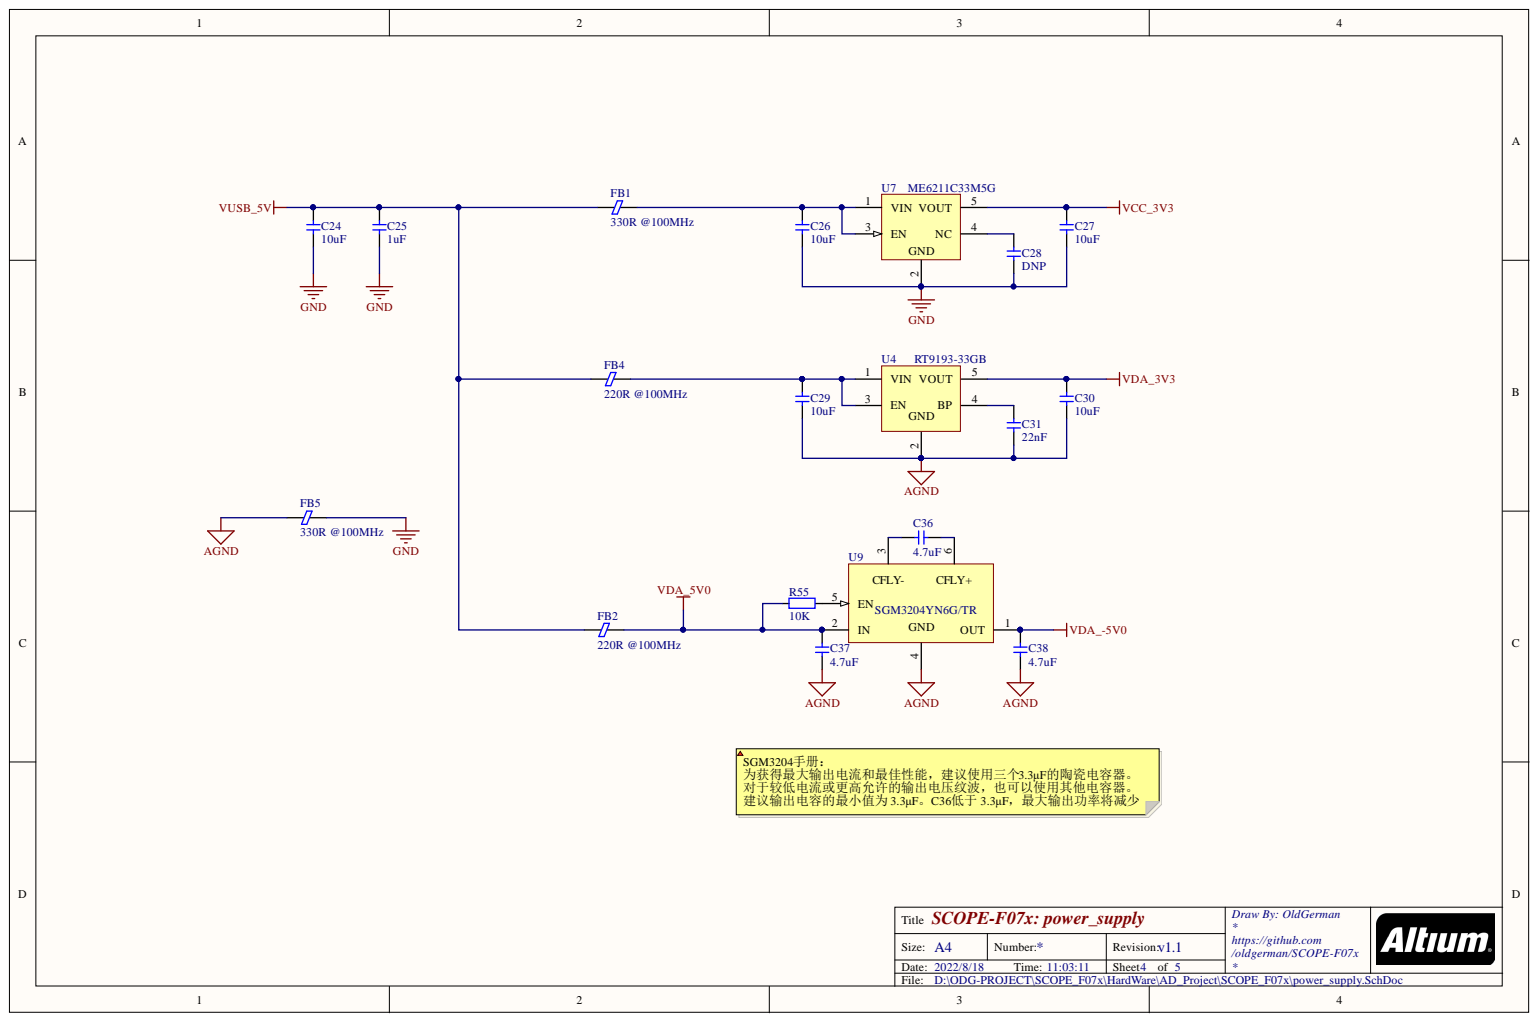
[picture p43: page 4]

SCOPE-F0 7x: p ower_supply T i t l e | D r aw By: O l d Germ a n *h t tp s://g i t h u b.co m /o l dgerm a n/SCO P E-F 0 7x *

A4 Size: | * N umber: | v 1.1 Rev i s i o n :

/ / T ime: : : | | Sheet o f

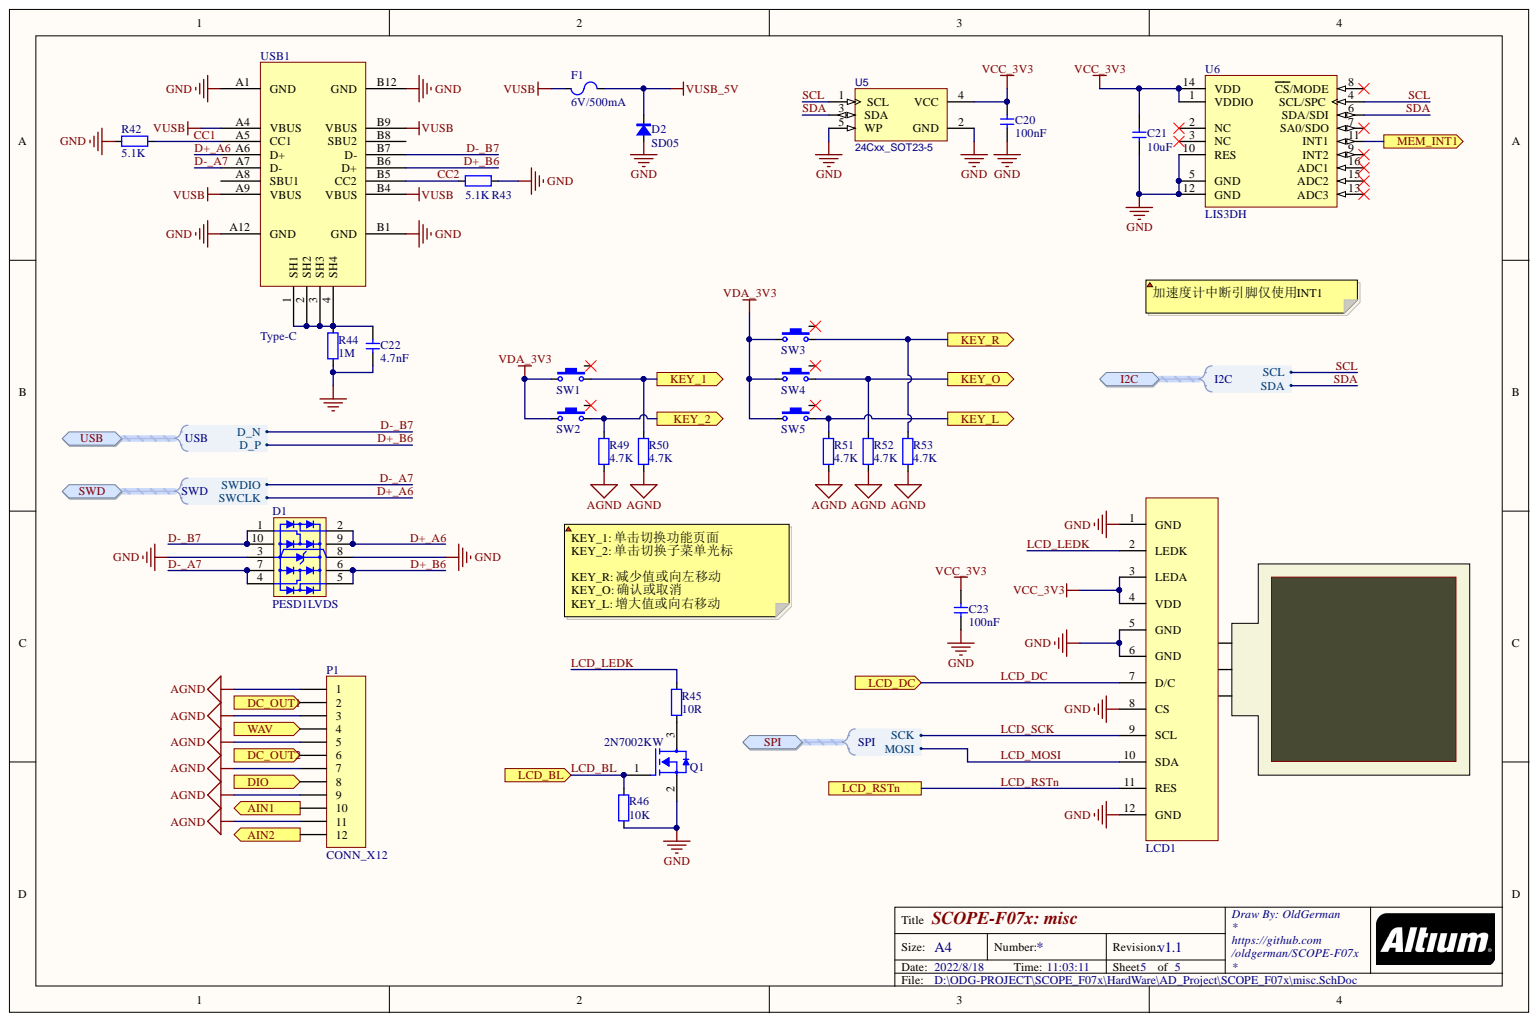
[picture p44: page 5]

SCOPE-F07x: misc Title | Draw By: OldGerman * https://github.com/oldgerman/SCOPE-F07x

A4 Size: | * Number: | v1.1 Revision:

D:\ODG-PROJECT\SCOPE_F07x\HardWare\AD_Project\SCOPE_F07x\misc.SchDoc

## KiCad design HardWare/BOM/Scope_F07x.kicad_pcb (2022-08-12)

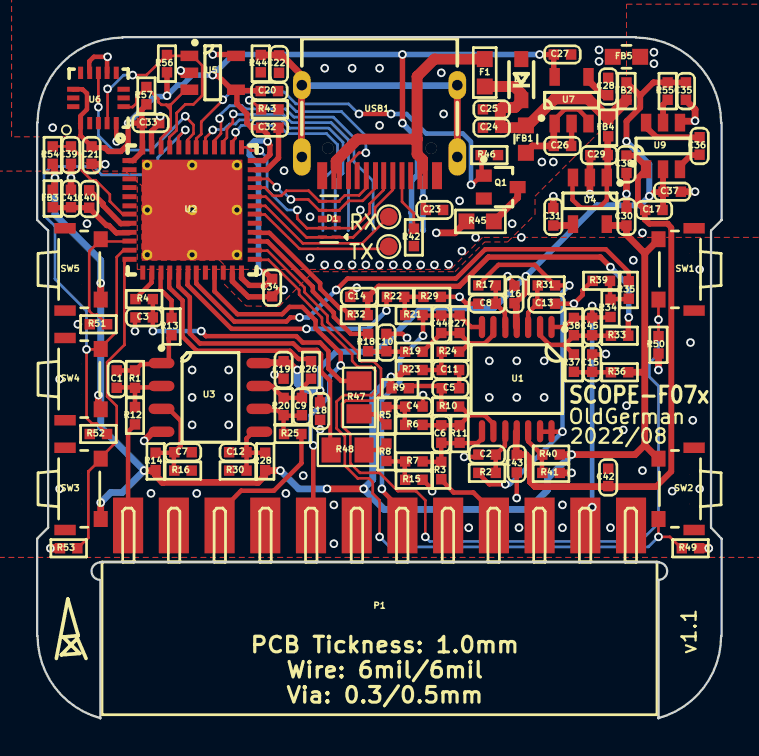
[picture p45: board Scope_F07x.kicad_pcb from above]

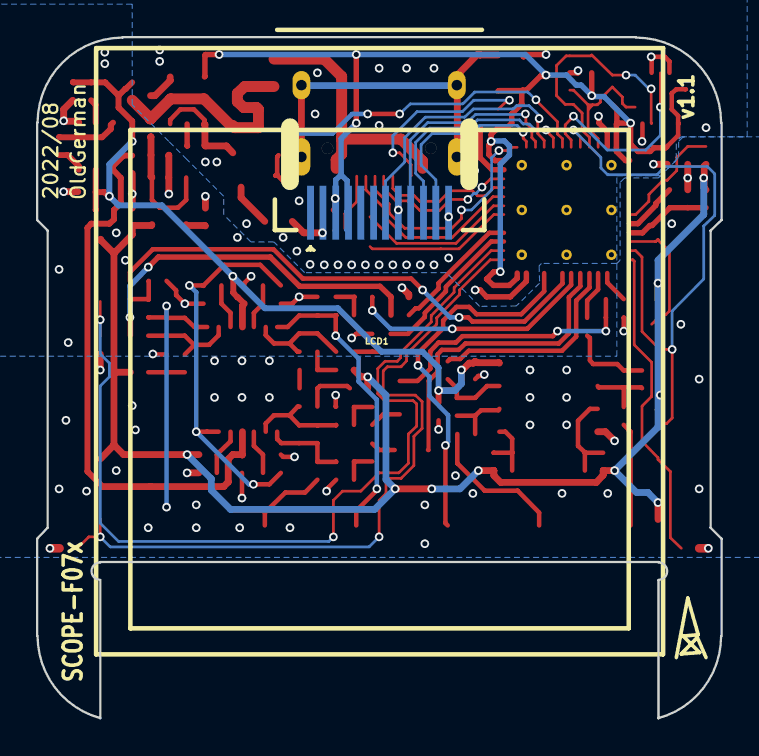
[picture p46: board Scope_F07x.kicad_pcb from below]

Board: 2 copper layers, 38.0 x 37.8 mm, 129 parts (2 on the bottom side), 80 nets.

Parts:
C1, C9: 0.5pF; C0402_1
C2, C5, C8, C10, C11, C13, C14, C15, C25, C40: 1uF; C0402_1
C3, C4: 150pF; C0402_1
C6: 39pF; C0402_1
C7, C12, C36, C37, C38: 4.7uF; C0402_1
C16, C17, C19, C20, C23, C32, C33, C34, C39, C43: 100nF; C0402_1
C18, C21, C24, C26, C27, C29, C30, C35, C41, C42: 10uF; C0402_1
C22: 4.7nF; C0402_1
C28, C44, C45: DNP; C0402_1
C31: 22nF; C0402_1
D1: PESD1LVDS; DFN2510-10_SOT1165-1_1
D2: SD05; SOD-323_1
F1: 6V/500mA; FUSE0603_0.5MM_1
FB1: 330R @100MHz; FER0603_2
FB2, FB3, FB4: 220R @100MHz; FER0402_1
FB5: 330R @100MHz; FER0603_1
LCD1: LCD_240x240; LCD-240X240-1.54INCH_FLUSH_F74
ODG1, ODG2: ODG_LOGO; ODG_LOGO_1
P1: CONN_X12; 2.54MM_FEMALE_1x12_180H_1
Q1: 2N7002KW; DIODES_SOT-323-3_1
R1, R20: 330K; R0402_1
R2, R7, R10, R17, R21, R31, R34: 1K; R0402_1
R3: 49.9R; R0402_1
R4: 536R; R0402_1
R5: 750R; R0402_1
R6: 270R; R0402_1
R8, R22, R24, R35, R37, R46, R54, R55: 10K; R0402_1
R9, R16, R18, R30, R32: 3.3K; R0402_1
R11: 4.3K; R0402_1
R12, R25, R44: 1M; R0402_1
R13, R26: 100R; R0402_1
R14, R28: 5.49K; R0402_1
R15, R23, R29, R36, R39: 2K; R0402_1
R19, R33: 1.65K; R0402_1
R27, R38, R40, R41: 12K; R0402_1
R42, R43: 5.1K; R0402_1
R45: 10R; R0603_1
R47, R48: 0R; R0805_1
R49, R50, R51, R52, R53, R56, R57: 4.7K; R0402_1
SW1, SW2, SW3, SW4, SW5: Button-2P+PAD; TACTILE_SWITCH_SMD_4.6x1.82x32
U1: OPA4197; ON_SEMI_TSSOP-14_948G_1
U2: STM32F072CBU6 / STM32F071CBU6; UFQFPN-48_7X7X0P55MM_VIA_1
U3: SGM8632; ANALOG_DEV_SOIC-8_R8_1
U4: RT9193-33GB; MICROCHIP_SOT-23-5_OT_1
U5: 24Cxx_SOT23-5; MICROCHIP_SOT-23-5_OT_1
U6: LIS3DH; LGA-16-3X3_1
U7: ME6211C33M5G; ANALOG_TSOT-23-5_UJ-5_1
U9: SGM3204YN6G/TR; MICROCHIP_SOT-23-6_M6_1
USB1: Type-C; Type-C-TOP_1

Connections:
AGND: C2.2, C3.1, C4.1, C5.1, C7.1, C8.2, C10.1, C11.1, C12.1, C13.2, C14.1, C15.1, C16.1, C18.1, C19.1, C29.2, C30.2, C31.2, C35.1, C37.2, C38.2, C39.2, C40.2, C41.2, C42.1, C43.1, FB5.2, P1.1, P1.3, P1.5, P1.7, P1.9, P1.11, R15.1, R16.1, R29.1, R30.1, R39.1, R41.1, R49.2, R50.2, R51.2, R52.2, R53.2, U2.8, U3.4, U4.2, U9.4
CC1: R42.1, USB1.A5
CC2: R43.2, USB1.B5
D+_A6: D1.2, D1.9, U2.37, USB1.A6
D+_B6: D1.5, D1.6, U2.33, USB1.B6
D-_A7: D1.4, D1.7, U2.34, USB1.A7
D-_B7: D1.1, D1.10, U2.32, USB1.B7
GND: C20.2, C21.2, C22.2, C23.1, C24.2, C25.2, C26.2, C27.2, C28.2, C32.2, C33.2, C34.2, D1.3, D1.8, D2.1, FB5.1, LCD1.1, LCD1.5, LCD1.6, LCD1.8, LCD1.12, Q1.2, R42.2, R43.1, R44.2, R46.1, U2.23, U2.35, U2.47, U2.49, U2.49_1, U2.49_2, U2.49_3, U2.49_4, U2.49_5, U2.49_6, U2.49_7, U2.49_8, U2.49_9, U5.2, U5.5, U6.5, U6.10, U6.12, U7.2, USB1.A1, USB1.A12, USB1.B1, USB1.B12
KEY_L: R51.1, SW5.2, U2.10
KEY_O: R52.1, SW4.2, U2.11, U2.44
KEY_R: R53.1, SW3.2, U2.12
LCD_BL: Q1.1, R46.2, U2.42
LCD_DC: LCD1.7, U2.40
LCD_LEDK: LCD1.2, R45.2
LCD_MOSI: LCD1.10, U2.41
LCD_RSTn: LCD1.11, U2.38
LCD_SCK: LCD1.9, U2.39
MEM_SCL: R56.2, U2.45, U5.1, U6.4
MEM_SDA: R57.2, U2.46, U5.3, U6.6
NetC1_1: C1.1, R1.2, R13.1, U3.1
NetC1_2: C1.2, R1.1, R12.2, U3.2
NetC2_1: C2.1, R2.2, U1.10
NetC3_2: C3.2, R4.2, R47.1
NetC4_2: C4.2, R5.2, R6.1
NetC5_2: C5.2, R9.2, R10.1
NetC6_1: C6.1, R3.1, R7.2, R11.2, U1.8
NetC6_2: C6.2, R6.2, R10.2, R11.1, U1.9
NetC7_2: C7.2, R14.2, R16.2, U3.3
NetC8_1: C8.1, R17.2, U1.5
NetC9_1: C9.1, R20.2, R26.1, U3.7
NetC9_2: C9.2, R20.1, R25.2, U3.6
NetC10_2: C10.2, R18.2, R19.1
NetC11_2: C11.2, R23.2, R24.1
NetC12_2: C12.2, R28.2, R30.2, U3.5
NetC13_1: C13.1, R31.2, U1.3
NetC14_2: C14.2, R32.2, R33.1
NetC15_2: C15.2, R36.2, R37.1
NetC22_1: C22.1, R44.1, USB1.1, USB1.2, USB1.3, USB1.4
NetC26_1: C26.1, FB1.2, U7.1, U7.3
NetC28_1: C28.1, U7.4
NetC29_1: C29.1, FB4.2, U4.1, U4.3
NetC31_1: C31.1, U4.4
NetC36_1: C36.1, U9.3
NetC36_2: C36.2, U9.6
NetC39_1: C39.1, R54.2, U2.7
NetC40_1: C40.1, C41.1, FB3.2, U2.9
NetC44_1: C44.1, P1.6, R21.2, R27.2, U1.7
NetC44_2: C44.2, R19.2, R24.2, R27.1, U1.6
NetC45_1: C45.1, P1.2, R34.2, R38.2, U1.1
NetC45_2: C45.2, R33.2, R37.2, R38.1, U1.2
NetP1_4: P1.4, R3.2
NetP1_8: P1.8, U2.21
NetP1_10: P1.10, R25.1
NetP1_12: P1.12, R12.1
NetQ1_3: Q1.3, R45.1
NetR4_1: R4.1, U2.14
NetR5_1: R5.1, R47.2
NetR7_1: R7.1, R8.2, R15.2
NetR8_1: R8.1, R48.1
NetR13_2: R13.2, U2.15
NetR18_1: R18.1, U2.27
NetR21_1: R21.1, R22.2, R29.2
NetR22_1: R22.1, U2.18
NetR26_2: R26.2, U2.16
NetR32_1: R32.1, U2.28
NetR34_1: R34.1, R35.2, R39.2
NetR35_1: R35.1, U2.19
NetR40_2: R40.2, R41.2, U1.12
NetR48_2: R48.2, U2.17
NetR49_1: R49.1, SW2.2, U2.25
NetR50_1: R50.1, SW1.2, U2.26
NetR55_1: R55.1, U9.5
NetU2_43: U2.43, U6.11
VCC_3V3: C20.1, C21.1, C23.2, C27.1, C32.1, C33.1, C34.1, LCD1.3, LCD1.4, R56.1, R57.1, U2.1, U2.24, U2.36, U2.48, U5.4, U6.1, U6.14, U7.5
VDA_1V65: R2.1, R17.1, R31.1, U1.13, U1.14
VDA_3V3: C30.1, FB3.1, R9.1, R14.1, R23.1, R28.1, R36.1, R40.1, R54.1, SW1.1, SW2.1, SW3.1, SW4.1, SW5.1, U4.5
VDA_5V0: C16.2, C17.2, C18.2, C19.2, C35.2, C37.1, FB2.1, R55.2, U1.4, U3.8, U9.2
VDA_-5V0: C17.1, C38.1, C42.2, C43.2, U1.11, U9.1
VUSB: F1.1, USB1.A4, USB1.A9, USB1.B4, USB1.B9
VUSB_5V: C24.1, C25.1, D2.2, F1.2, FB1.1, FB2.2, FB4.1

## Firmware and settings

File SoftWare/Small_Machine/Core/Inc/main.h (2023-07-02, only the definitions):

#define Key_1_Pin GPIO_PIN_13
#define Key_1_GPIO_Port GPIOB
#define Key_2_Pin GPIO_PIN_12
#define Key_2_GPIO_Port GPIOB
#define Key_R_Pin GPIO_PIN_2
#define Key_R_GPIO_Port GPIOA
#define Key_O_Pin GPIO_PIN_1
#define Key_O_GPIO_Port GPIOA
#define Key_L_Pin GPIO_PIN_0
#define Key_L_GPIO_Port GPIOA
#define LCD_DC_Pin GPIO_PIN_4
#define LCD_DC_GPIO_Port GPIOB
#define LCD_SCL_Pin GPIO_PIN_3
#define LCD_SCL_GPIO_Port GPIOB
#define LCD_RST_Pin GPIO_PIN_15
#define LCD_RST_GPIO_Port GPIOA
#define LCD_SDA_Pin GPIO_PIN_5
#define LCD_SDA_GPIO_Port GPIOB
#define LCD_BL_Pin GPIO_PIN_6
#define LCD_BL_GPIO_Port GPIOB

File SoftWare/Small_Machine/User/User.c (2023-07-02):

#include "User.h"


/*
	当前系统时钟为72M
	
	SPI原预分频为 SPI_BAUDRATEPRESCALER_4
	PLL锁相环原PLLMUL为 RCC_PLL_MUL6
*/
/*-----------------------------------------------------------------------------------------------------------------*/
System_State System = Oscilloscope;

uint8_t Page_Init = 1;
uint8_t System_Select[5] = {0};

uint8_t LCD_Clean_Flag = 0;
uint8_t Wave_Change_Flag = 1; //上电默认开启信号发生器
uint8_t PWM_Change_Flag = 1;  //上电默认开启PWM发生器
uint8_t Power_DC_Flag = 1;    //上电默认开启PowerDC输出

void System_Change_State(System_State State)
{
	System = State;
	System_Select[State] = 0;
	LCD_Clean_Flag = 1;
	Page_Init = 1;
	
	//信号发生器光标归位
	Wave_Vpp_Select = 0;
	Wave_Freq_Select = 0;
	Wave_Offset_Select = 0;
	
	//PWM发生器光标归位
	PWM_Freq_Select = 0;
	PWM_Duty_Select = 0;
	
	//Power DC输出光标归位
	Power_Select = 0;
	Power_voltage_Select = 0;
	Power_Out_Select = 0;
}


void LCD_Handle(void)
{
	switch(System)
	{
		case Oscilloscope:
		{
			if(Page_Init)
			{
				Page_Init = 0;
				Oscilloscope_Init();
			}
			Oscilloscope_Show_Wave();
			Oscilloscope_Show_Information(System_Select[Oscilloscope]);
			break;
		}
		
		case Spectrum:
			if(Page_Init)
			{
				Page_Init = 0;
				Spectrum_Init();
			}
			Spectrum_Show_Wave();
			Spectrum_Show_Information(System_Select[Spectrum]);
			break;
		
		case FunctionGen:
			if(Page_Init)
			{
				Page_Init = 0;
				Wave_Generate_UI();
			}
			Wave_Show_Information(System_Select[FunctionGen]);
			break;
			
		case PWM_Generate:
			if(Page_Init)
			{
				Page_Init = 0;
				PWM_Generate_UI();
			}
			PWM_Show_Information(System_Select[PWM_Generate]);
			break;
		
		case PowerDC:
			if(Page_Init)
			{
				Page_Init = 0;
				Power_DC_UI();
			}
			Power_Show_Information(System_Select[PowerDC]);
			break;
		
		default:
			break;
	}
}

void Key_Handle(void)
{
	static Key_Type Key[5] = {0};
	Get_Key(Key);
	
	switch(System)
	{
		case Oscilloscope:
		{
			if(Get_Rise(Key2))
				System_Select[Oscilloscope] = ((System_Select[Oscilloscope] < 2) ? (System_Select[Oscilloscope] + 1) : (0));
			
			if(Get_Rise(KeyL) || Get_Long_Tri(KeyL))
			{
				if(System_Select[Oscilloscope] == 1)//电压刻度-
				{
					Voltage_Div = ((Voltage_Div > 0) ? (Voltage_Div - 1) : (Voltage_Div));
					if(Scan_Show)
						Oscilloscope_Clean();
				}
				else if(System_Select[Oscilloscope] == 2)//时间刻度-
				{
					Time_Div = ((Time_Div > 0) ? (Time_Div - 1) : (Time_Div));
					Set_ADC_Samp_Rate(Time_Div);
				}
			}
			
			if(Get_Rise(KeyR) || Get_Long_Tri(KeyR))
			{
				if(System_Select[Oscilloscope] == 1)//电压刻度+
				{
					Voltage_Div = ((Voltage_Div < 6) ? (Voltage_Div + 1) : (Voltage_Div));
					if(Scan_Show)
						Oscilloscope_Clean();
				}
				else if(System_Select[Oscilloscope] == 2)//时间刻度+
				{
					Time_Div = ((Time_Div < 17) ? (Time_Div + 1) : (Time_Div));
					Set_ADC_Samp_Rate(Time_Div);
				}
			}
			
			if(Get_Rise(Key1))
			{
				Oscilloscope_Deinit();
				System_Change_State(Spectrum);
			}
			break;
		}
		
		case Spectrum:
		{
			if(Get_Rise(Key2))
				System_Select[Spectrum] = ((System_Select[Spectrum] < 2) ? (System_Select[Spectrum] + 1) : (0));
			
			if(Get_Rise(KeyL) || Get_Long_Tri(KeyL))
			{
				if(System_Select[Spectrum] == 1)//电压刻度-
					Freq_Voltage_Div = ((Freq_Voltage_Div > 0) ? (Freq_Voltage_Div - 1) : (Freq_Voltage_Div));
				else if(System_Select[Spectrum] == 2)//频率刻度-
				{
					Freq_Div = ((Freq_Div > 0) ? (Freq_Div - 1) : (Freq_Div));
					Set_FFT_Samp_Rate(Freq_Div);
				}
			}
			
			if(Get_Rise(KeyR) || Get_Long_Tri(KeyR))
			{
				if(System_Select[Spectrum] == 1)//电压刻度+
					Freq_Voltage_Div = ((Freq_Voltage_Div < 6) ? (Freq_Voltage_Div + 1) : (Freq_Voltage_Div));
				else if(System_Select[Spectrum] == 2)//频率刻度+
				{
					Freq_Div = ((Freq_Div < 7) ? (Freq_Div + 1) : (Freq_Div));
					Set_FFT_Samp_Rate(Freq_Div);
				}
			}
			
			if(Get_Rise(Key1))
			{
				FFT_Deinit();
				System_Change_State(FunctionGen);
			}
			break;
		}
		
		case FunctionGen:
		{
			float Voltage_Plus[2] = {1.0,0.1};
			
			if(Get_Rise(Key2))
			{
				System_Select[FunctionGen] = ((System_Select[FunctionGen] < 3) ? (System_Select[FunctionGen] + 1) : (0));
				Wave_Vpp_Select = 0;
				Wave_Freq_Select = 0;
				Wave_Offset_Select = 0;
			}
			
			switch(System_Select[FunctionGen])
			{
				case 0://调节输出波形
				{
					if(Get_Rise(KeyR))
					{
						Wave_Info.Wave = (Wave_Type)((Wave_Info.Wave < 2) ? (Wave_Info.Wave + 1) : (Wave_Info.Wave));
						Wave_Change_Flag = 1;
					}
					if(Get_Rise(KeyL))
					{
						Wave_Info.Wave = (Wave_Type)((Wave_Info.Wave > 0) ? (Wave_Info.Wave - 1) : (Wave_Info.Wave));
						Wave_Change_Flag = 1;
					}
					break;
				}
				
				case 1://调节输出VPP
				{
					if(Get_Rise(KeyO))
						Wave_Vpp_Select = ((Wave_Vpp_Select < 1) ? (Wave_Vpp_Select + 1) : (0));
					
					if(Get_Rise(KeyR) || Get_Long_Tri(KeyR))
					{
						if(Wave_Info.VPP + Voltage_Plus[Wave_Vpp_Select] <= 4.0)
							Wave_Info.VPP += Voltage_Plus[Wave_Vpp_Select];
						Wave_Change_Flag = 1;
					}
					
					if(Get_Rise(KeyL) || Get_Long_Tri(KeyL))
					{
						if(Wave_Info.VPP - Voltage_Plus[Wave_Vpp_Select] >= -4.0)
							Wave_Info.VPP -= Voltage_Plus[Wave_Vpp_Select];
						Wave_Change_Flag = 1;
					}
					break;
				}
				
				case 2://调节输出Freq
				{
					float Freq_Plus_Num[5][4] = 
					{
						{0.1,1},
						{1,10,100},
						{10,100,1000},
						{100,1000,10000},
						{1000,10000},
					};
					
					if(Wave_Freq_Select > Freq_Max_Num)
						Wave_Freq_Select = 0;
					
					if(Get_Rise(KeyO))
						Wave_Freq_Select = ((Wave_Freq_Select < Freq_Max_Num) ? (Wave_Freq_Select + 1) : (0));
					
					if(Get_Rise(KeyR) || Get_Long_Tri(KeyR))
					{
						if(Wave_Info.Freq + Freq_Plus_Num[Wave_Freq_Level][Freq_Max_Num - Wave_Freq_Select] <= 100000.0)
							Wave_Info.Freq += Freq_Plus_Num[Wave_Freq_Level][Freq_Max_Num - Wave_Freq_Select];
						Wave_Change_Flag = 1;
					}
					
					if(Get_Rise(KeyL) || Get_Long_Tri(KeyL))
					{
						if(Wave_Info.Freq - Freq_Plus_Num[Wave_Freq_Level][Freq_Max_Num - Wave_Freq_Select] >= 0.05)
							Wave_Info.Freq -= Freq_Plus_Num[Wave_Freq_Level][Freq_Max_Num - Wave_Freq_Select];
						else if(Wave_Info.Freq == 1)
							Wave_Info.Freq -= 0.1;
						Wave_Change_Flag = 1;
					}
					
					break;
				}
				
				case 3://调节输出Offset
				{
					if(Get_Rise(KeyO))
						Wave_Offset_Select = ((Wave_Offset_Select < 1) ? (Wave_Offset_Select + 1) : (0));
				
					if(Get_Rise(KeyR) || Get_Long_Tri(KeyR))
					{
						if(Wave_Info.Offset + Voltage_Plus[Wave_Offset_Select] <= 4.0)
							Wave_Info.Offset += Voltage_Plus[Wave_Offset_Select];
						Wave_Change_Flag = 1;
					}
					
					if(Get_Rise(KeyL) || Get_Long_Tri(KeyL))
					{
						if(Wave_Info.Offset - Voltage_Plus[Wave_Offset_Select] >= -4.0)
							Wave_Info.Offset -= Voltage_Plus[Wave_Offset_Select];
						Wave_Change_Flag = 1;
					}
					break;
				}
				
				default:
					break;
			}
			
			if(Get_Rise(Key1))
				System_Change_State(PWM_Generate);
			break;
		}
		
		case PWM_Generate:
		{
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

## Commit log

2022-08-02 添加EETree仓库链接
2022-08-02 补充README说明
    [Scope.kicad_pcb]
2022-08-10 PCB更新v1.1版本
    [SCOPE_F07x.PrjPcb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]
2022-08-10 添加鸣谢
2022-08-10 添加README.pdf
2022-08-10 添加Gerber,移动BOM目录
    [Scope_F07x.kicad_pcb]
2022-08-11 R4从750R修改为536R，原因是DAC输出缓冲器不是轨到轨，通过减小R4增加增益解决
    [Scope_F07x.kicad_pcb, analog.SchDoc]
2022-08-11 移除部分手册
2022-08-12 RT9393更正为RT9193，添加3d打印模型
    [CASE_BOTTOM_1_0812-1232.STL, CASE_TOP_1_0812_1233.STL, SW_x2_1.STL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]
2022-08-12 补充README，添加License
2022-08-12 补充README
2022-08-12 添加SW_Project、LTspice
    [1.54 TFT IPS-12P-Flat Flush Mount.SLDPRT, 2.54MM_Pin Header_Female_1x12.SLDPRT, CASE_BOTTOM_1.SLDPRT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]
2022-08-12 移除NANO文件夹
2022-08-12 更新bin
2022-08-14 更新750R换536R的固件，发生信号的摆幅可以到-4V~4V
2022-08-14 功能测试-添加波形发生
2022-08-16 功能测试-添加图片
2022-08-18 修正原理图注释错误
    [analog.SchDoc]
2023-04-26 2023-04-26_02:46 修复CH2频率计不显示和printf动态内存死机问题
    [power_supply.SchDoc]

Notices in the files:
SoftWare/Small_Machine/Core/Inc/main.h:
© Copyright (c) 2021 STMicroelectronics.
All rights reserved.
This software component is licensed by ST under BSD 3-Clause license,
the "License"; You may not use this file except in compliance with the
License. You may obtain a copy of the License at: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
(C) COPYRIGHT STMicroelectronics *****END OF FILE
